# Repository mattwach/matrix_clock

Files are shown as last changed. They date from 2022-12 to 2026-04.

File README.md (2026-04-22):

# matrix_clock
> "I DON’T EVEN SEE THE CODE ANYMORE" - The Matrix.  

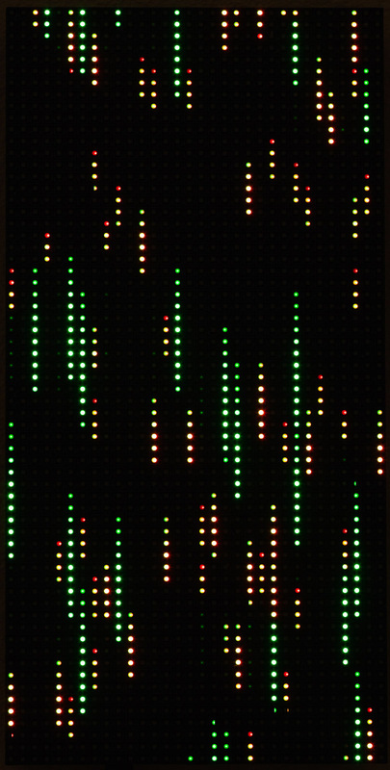
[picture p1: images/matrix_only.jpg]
matrix clock


Shown above is a clock that presents the current time on an 64x32 RGB LED
matrix.  The clock has other selectable modes, including a view that includes
the numbers:

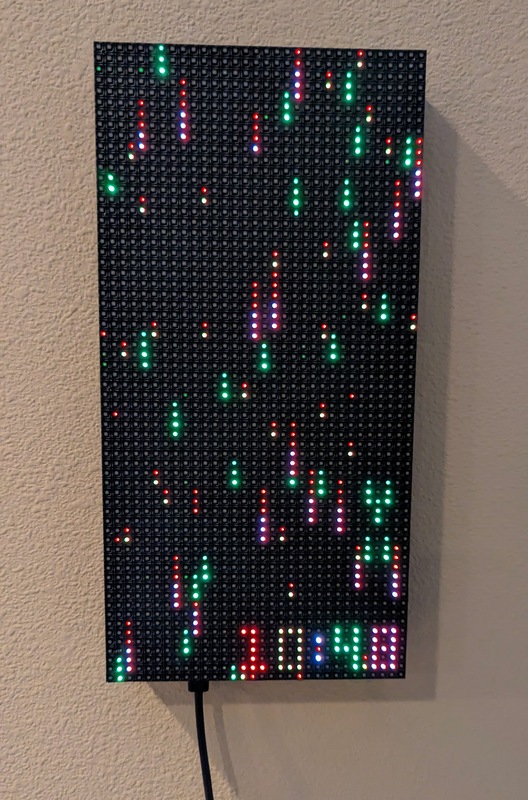
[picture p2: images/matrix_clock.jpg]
matrix clock


and some other selectable views:

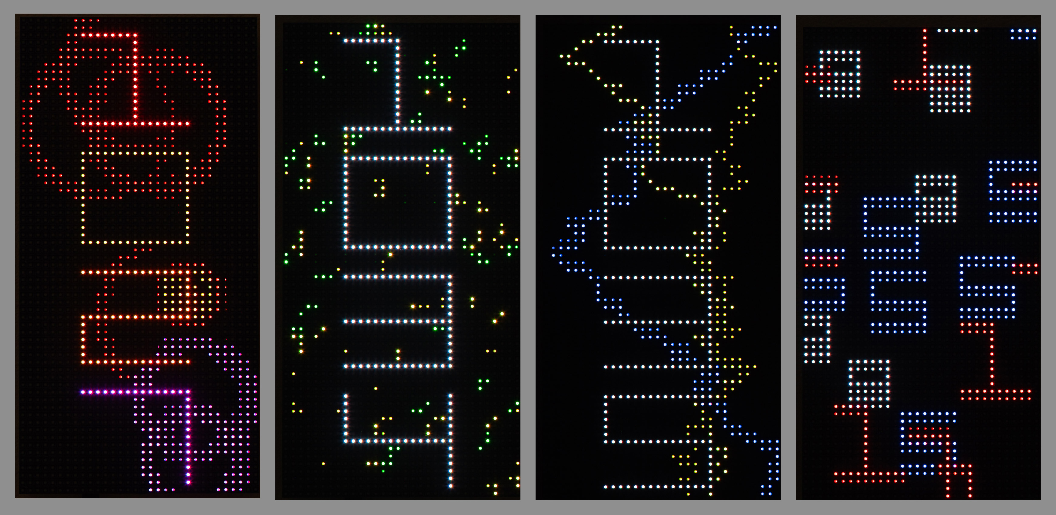
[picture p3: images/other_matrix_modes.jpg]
matrix clock


Although the images above give you a basic idea, they can't show you the
dynamic range of the LED or the visual impression of 200 FPS animations,

The project's firmware is designed to easily incorporate support for other
hardware configurations.  Included is a 8x8 "Dotstar" matrix version that was my
first version:

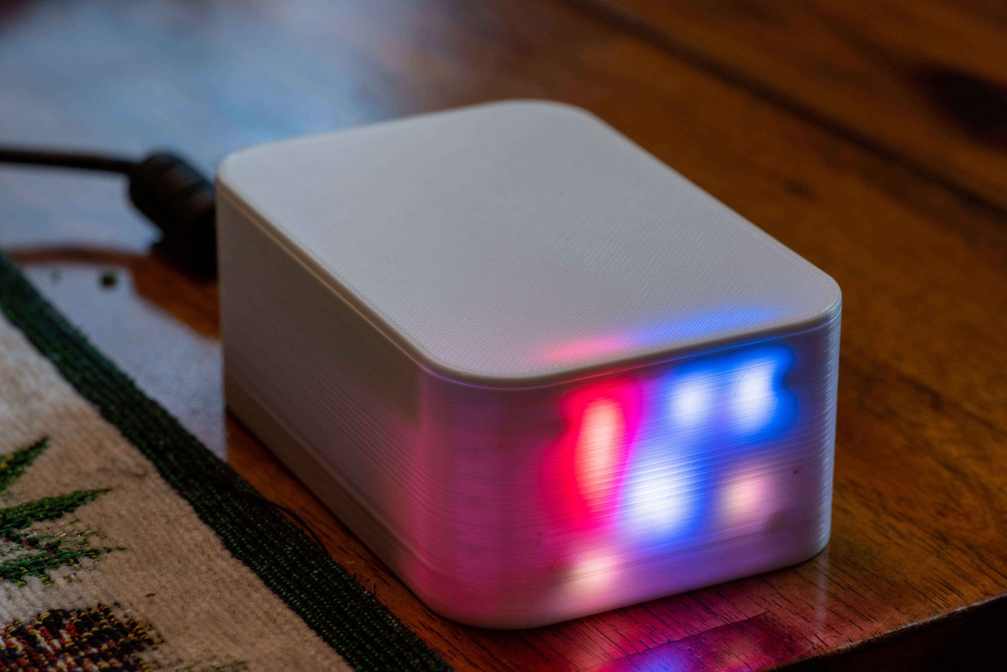
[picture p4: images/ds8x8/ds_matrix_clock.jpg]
matrix clock


*This document* focuses on the newer 62x32-based model, which I prefer.  If you
want to learn more details on the 8x8 build, I have a separate document
for it [here](README_dotstar_8x8.md).

In the upcoming sections, I explain how I built the clock.  I also
explain how to modify the design in different ways.

# Parts List

You can of course modify the design to use different ones.  Prices are "at time
of writing":

   * Microcontroller: [Raspberry PI Pico ($4)](https://www.adafruit.com/product/4864)
   * [LED Matrix 62x32: ($30)](https://www.amazon.com/waveshare-Displaying-Animation-Adjustable-Brightness/dp/B0B3W1PFY6)
     Note there are many vendors of this display - I assume they have similar
     interfaces.
   * Clock: [DS3231-based RTC module ($4)](https://www.amazon.com/HiLetgo-AT24C32-Arduino-Without-Battery/dp/B00LX3V7F0).
     This part is optional-but-recommended. The firmware can be built to use the
     Pi Pico clock libraries but you will lose battery backup and the time
     will drift more. 
   * Buttons: I used [2 6mm push buttons for control (<$1)](https://www.amazon.com/WOWOONE-12x12x7-3-Tactile-Momentary-Assortment/dp/B08JLWTQ3C)
     and one 6x3 SMD button for optional reset capability.
   * Connectors:
     * I used one 8x2 2.54 pitch male pin header to interface the Pico PCB with
       the matrix (using the usually-included interface cable)
     * I used a 2x1 angled 2.54 pitch pin header for connecting the LED to the
       PCB.
     * I used a 3x1 angled 2.54 pitch pin header for connecting the buttons to
       the PCB
   * I used a 220uF capacitor to reduce 5V noise.  Somewhat larger or smaller
     values should also work fine.
   * Circuit board for assembling components.
     * There are many options.  I ended up ordering a PCB from
       http://oshpark.com for the main board because my PCB layout needs a
       two-layer board.  I could have wired it up on perf board, but the large
       number of pin connections would have make it difficult to get a clean
       result.
     * There is a separate PCB for the buttons.  This board is very simple so
       any build technique should be straight-forward.  I used my CNC
       machine to cut a board within an hour.  If you order a main board, you
       might opt to bundle the button pcb with the order. 

Optional:

The LED display can pull over 3A if all LEDs are set to white.  The firmware I
wrote never does this and needs about 100-300 mA for most of the modes
(as-measured with a multimeter).  Thus I'm using the Pi Pico's VDD pin, which is
directly connected to USB power.  This connection should be limited to 500 mA or
less, thus I added the following electronic components to enforce the current
limit:

   * NCP380 current limiting IC
   * Two additional 1uf capacitors for stability.  I am using SMD but ceramic
     through-hole are also an option.

My hardware has this current protection but it has never activated outside of
testing thus one might argue that it's not needed.  If you plan to make your own
display modes, I suggest including the protection.

# Reading the clock

How can the clock be read when no numbers are shown?  By noting the colors and
speed of the particles.  Here is my color mapping for each number, as shown in
the time setting interface:

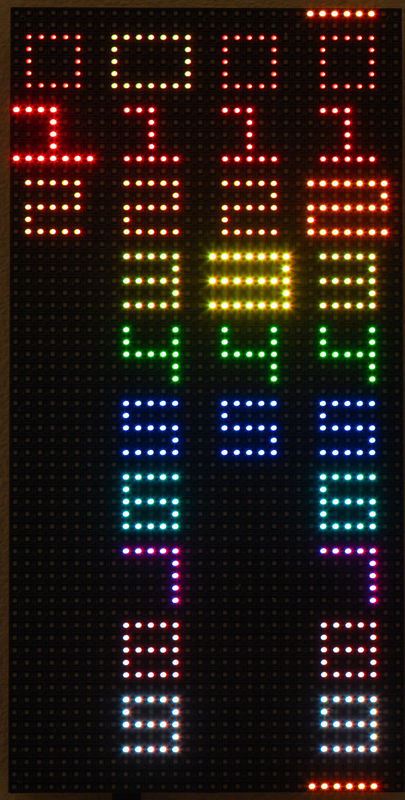
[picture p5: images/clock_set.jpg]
numbers


> Colors are defined in [src/colors.c](src/colors.c) if you would like to edit
> them.

# Feature Overview

This is a quick tour of the built in-features

## Power On

When you plug in the clock via any USB power source you will get a matrix clock
display that indicates the current time as-reported by the RTC clock hardware.

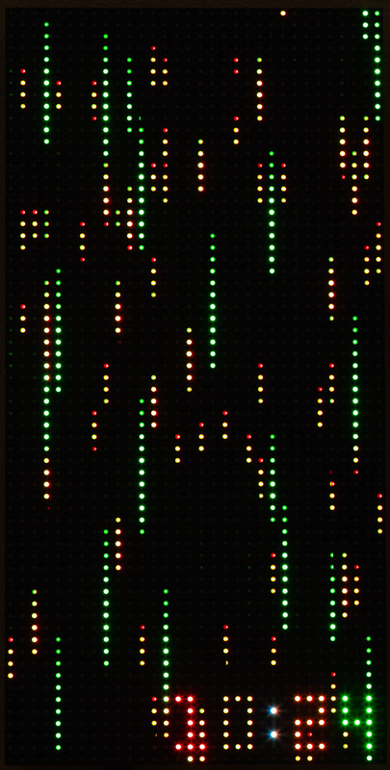
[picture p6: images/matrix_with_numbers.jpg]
matrix clock 2


## Setting the Time

The clock has two buttons on it's side: "set" and "increment". Pressing "set"
goes into time change mode where you can use "set" and "increment" to change
each time digit.

> You can also set the clock via the USB connection.

## Changing the Display Mode

If you press the "increment" button while the matrix is showing, the clock will
cycle through display modes.  Currently defined modes include:

* **Simple** Shows the time with no animations.  The color of the time
  changes throughout the day to approximate a sunrise/daytime/sunset color
  temperature.
* **Matrix With Numbers** The default
* **Matrix Only** For those who want a challenge
* **Bounce** Particles bounce around the numbers. 
* **Number Cascade** Digits fall from the top of the display to the bottom.  The
  size and speed of the digit represent the place in the time (hours vs
  minutes).
* **Waveform** Waveforms progress from the bottom of the display to the top at
  different speeds based on the time digit.
* **Drops** A water droplet effect appears behind the numbers.
* **Off -**  Useful if you want a darkened room.

Each display mode uses color as described earlier to accent the current time.

## Console Configuration

If you plug the clock into a computer, you can run a terminal emulator program
to access many additional settings.  In Linux, I use the "minicom" terminal
emulator and my command looks like this:

```bash
minicom -b 115200 -P /dev/ttyUSB0
```

> The serial device (`/dev/ttyUSB0`) can vary between computers and operating
> systems. 

Once started, you will see something like this:

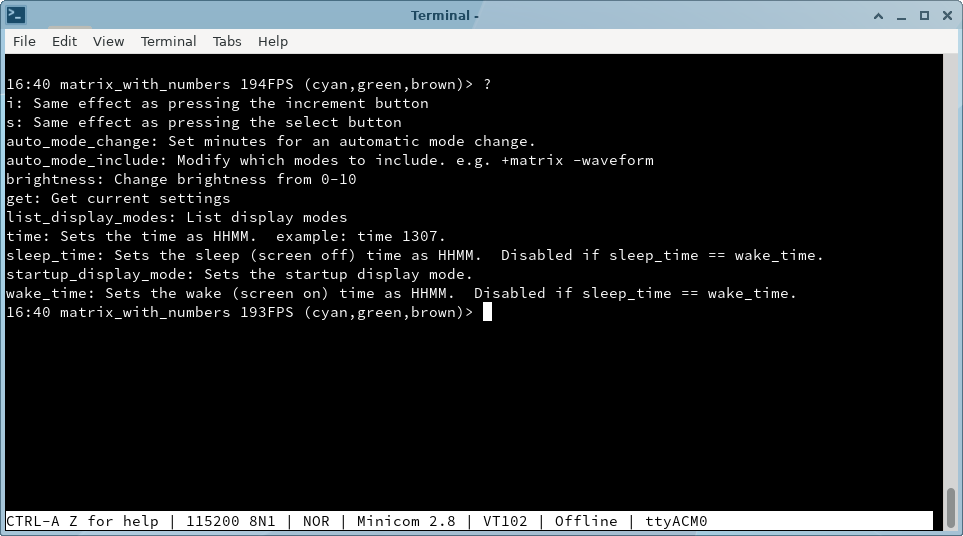
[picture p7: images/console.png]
console


> By default, `minicom` turns on local echo, making my typed characters appear
> twice.  `minicom` allows this to be turned off with `ctrl-a e`.

Type `help` or `?` for help.

# Build Instructions

## Electronics

Here is the schematic for the 64x32 version:

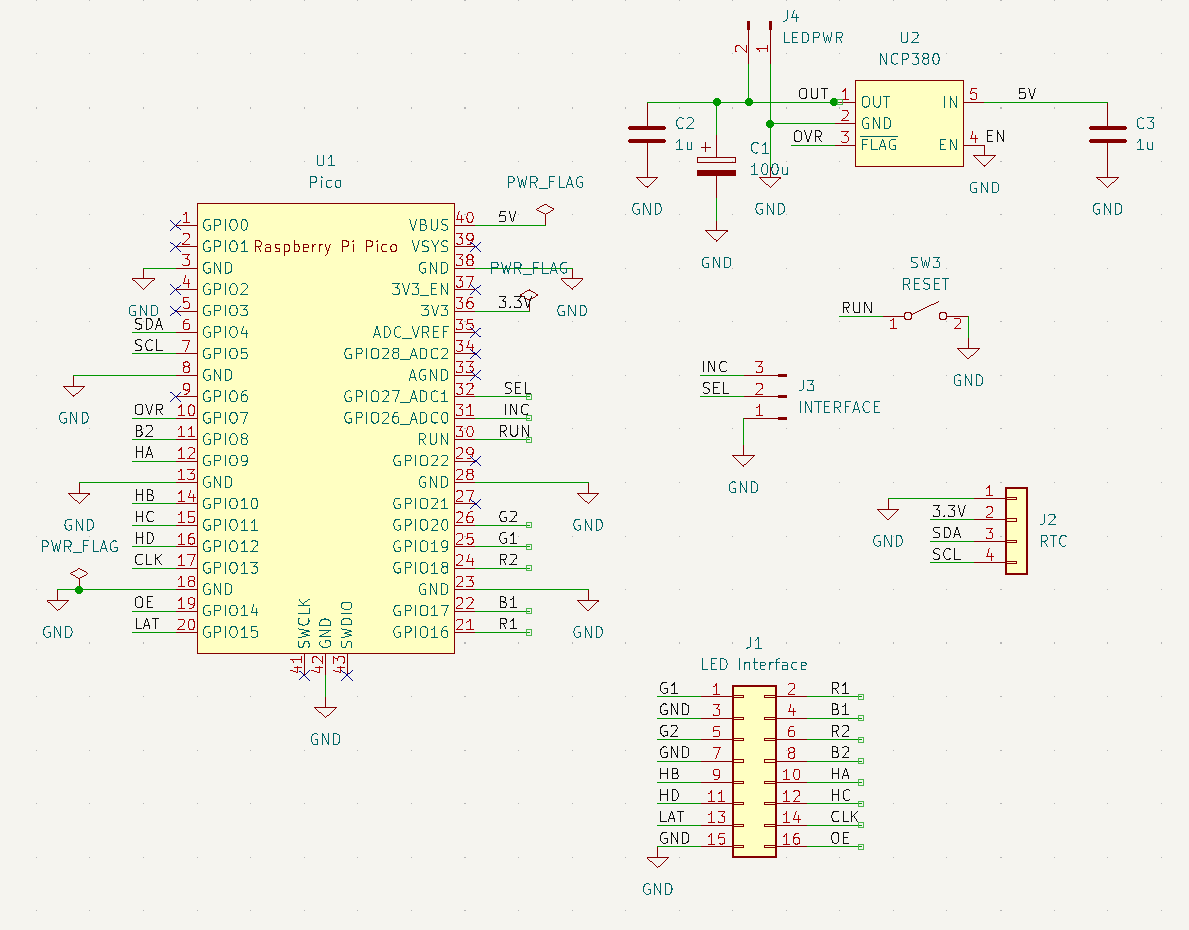
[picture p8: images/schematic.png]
schematic


Here is a description on major components and their purpose:

  - **Pi Pico**: This is the main controller
  - **RTC (Real Time Clock, Optional)**: This provides time to the Pico via an I2C connection.
    You could use alternate clock hardware as described in a later section.  In
    terms of the I2C connection, note that the RTC clock is powered by 3.3V
    instead of the specified 5V.  This is the easiest way to make the clock
    compatible with the 3.3V maximum voltage of the PI Pico.  If your RTC really
    does need 5V, there are solutions but the details are not the focus of this
    document.  Thus I suggest doing a Google search for "3.3 to 5V I2C" to learn
    more.
  - **64x32 matrix**: This is also a 5V part and is connected to the 5V VDD of the
    Pico, allowing ~500mA to be safely consumed by the panel.  The Pico is
    directly connected and will deliver 0-3.3V *signals* to the panel.  Unlike
    I2C for the RTC clock, the LED pins are high impedance inputs with no pullup
    thus there is no hardware risk in connecting them directly to the Pico.  The
    main risk is that the LED panel will not accept 3.3V as a legitimate "high"
    signal and thus it wont work.  For my panel 3.3V was accepted without a
    problem thus no level converters were needed.  I suspect this is the common
    scenario with these panels.
  - **100 uF-470 uF capacitor**.  The actual value is not important other than
    "big".  The purpose of the capacitor is to support the power requirements of
    the LED, which can be a "noisy" load, needing near zero current one moment
    and several hundred mA the next.
  - **Buttons**.  Select, increment and reset as described earlier.
  - **NCP380 current limiting chip (optional)**.  This chip provides insurance for
    the case where you one day decide to change the firmware to light up many
    LEDs and draw too much current.  If you really want to do support high
    current draw, you'll need to rework the power design so that the LED panel
    can be directly powered from a capable (3A+) source instead of VDD on the
    Pico.
    
> VDD on the Pico is a direct passthrough to the USB power so it's the
> USB regulator (wall adapter or computer) and the PCB traces of the Pico that are
> the main power bottlenecks.

> If you don't us use the NCP380, simply connect the Pico VDD pin directly to the LED.
> Keep the 100u capacitor for noise purposes.

In terms of layout, here is the KiCAD layout for the schematic above (with
ground plane hidden):

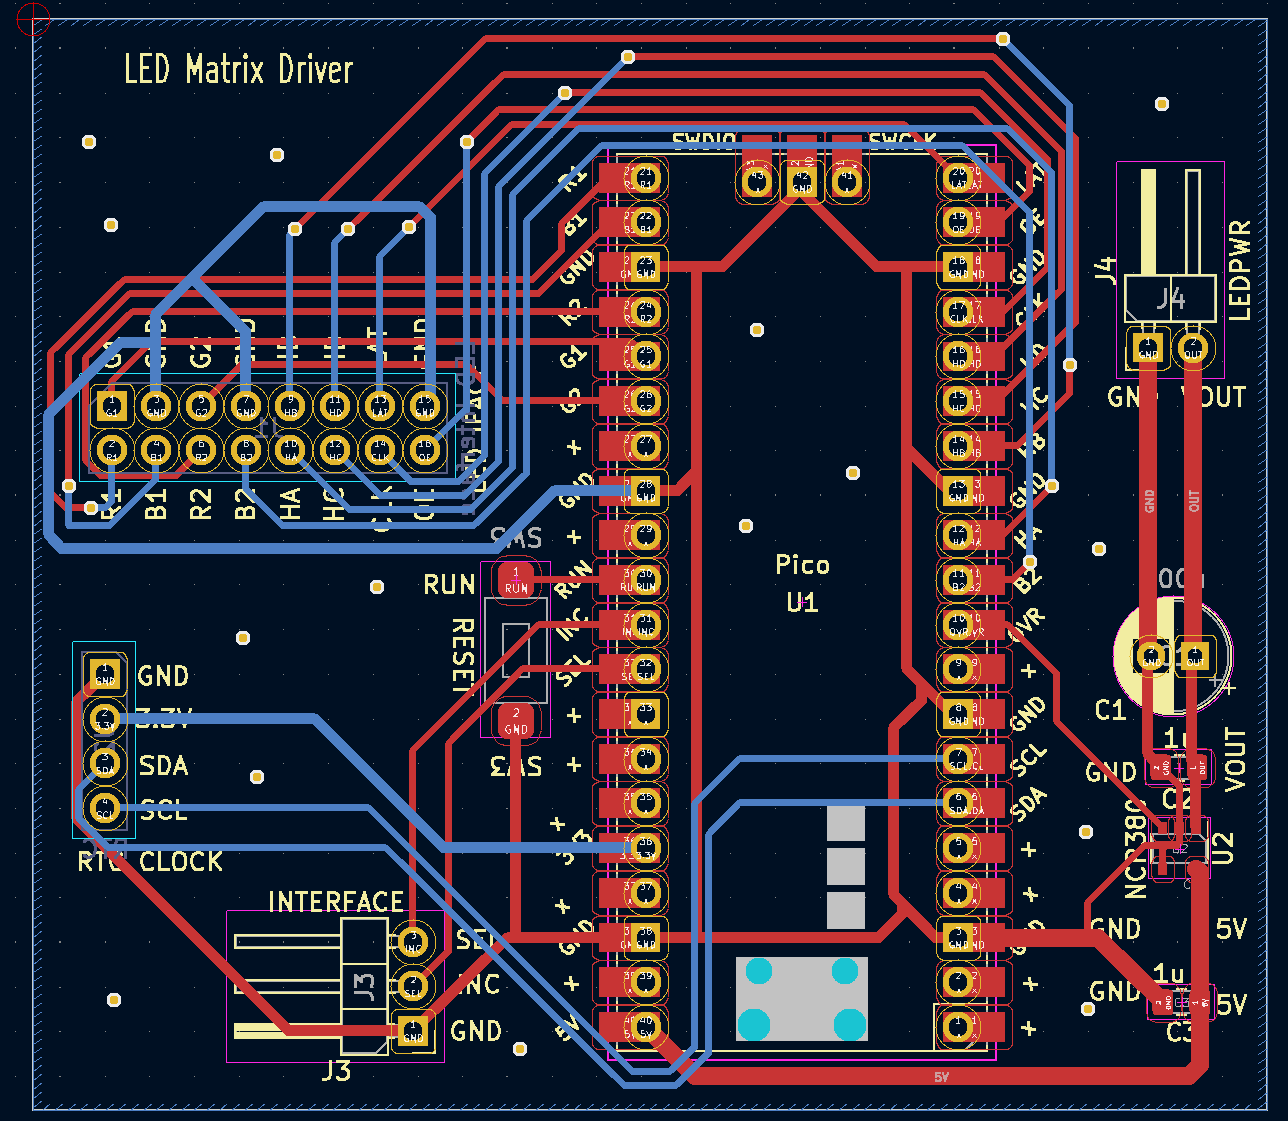
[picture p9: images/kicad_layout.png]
KiCAD layout


and here is a photo of the completed PCB.  Note that the capacitor can't be seen
because it is on the backside of the board:

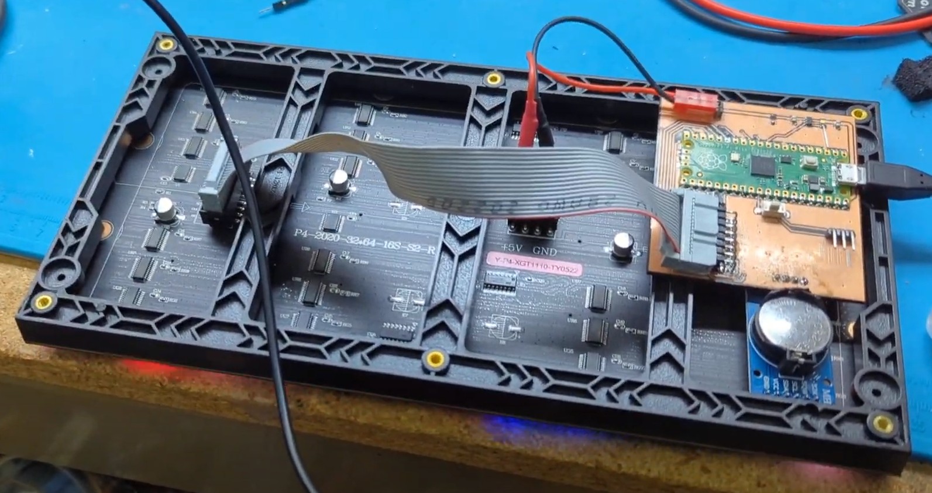
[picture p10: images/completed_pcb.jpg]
completed pcb


As for the buttons, here is the simple KiCAD layout:

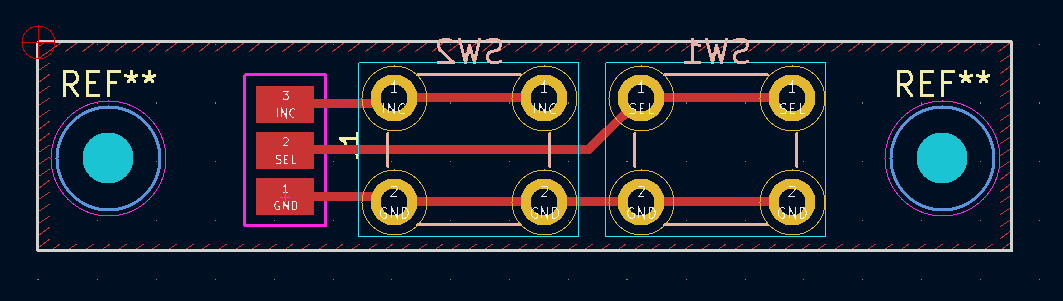
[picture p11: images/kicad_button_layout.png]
KiCAD button layout


and the finished board that I cut out with my CNC machine (just using a perf
board would also work fine):

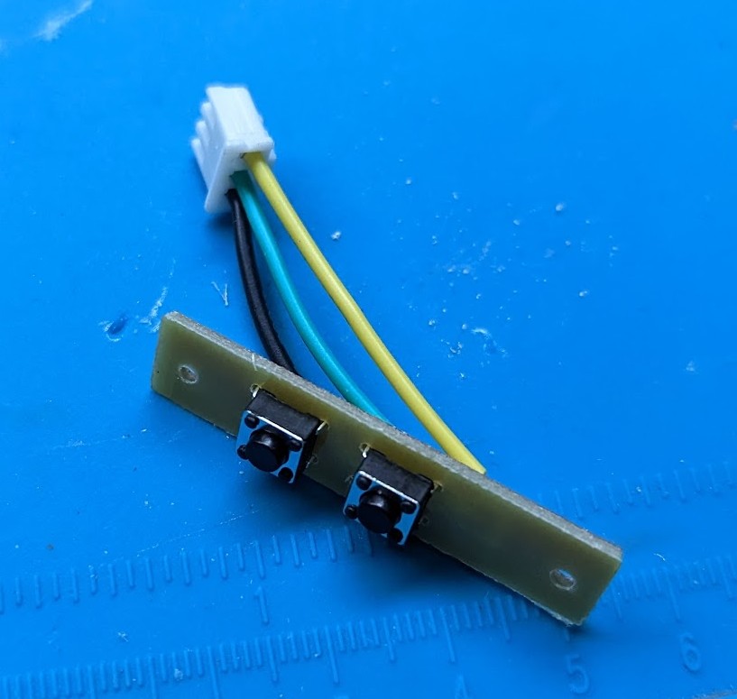
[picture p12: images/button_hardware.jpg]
button hardware


## Firmware

> TLDR: If you don't want to build the firmware (`matrix_clock_led_64x32.uf2`) 
yourself, I have a couple of precompiled versions under the
[firmware](firmware) directory.

Source files (written in C) are  provided in the [src/](src) directory.  If you
have never built PI Pico firmware before, run through the official [Getting
started with the Raspberry Pi
PICO](https://datasheets.raspberrypi.com/pico/getting-started-with-pico.pdf)
documentation first to get the needed tools up-and-running on your system.

The instructions for building the clock firmware are the same as the guide
linked above, but I created a small/simple [bootstrap.sh](src/bootstrap.sh)
script to lessen the number to needed steps:

```bash
./bootstrap.sh 
cd build/
make -j
```

I encourage you to view the contents of [bootstrap.sh](src/bootstrap.sh)
  yourself instead of blindly running it.  You'll see something like this:

```bash
$ cat bootstrap.sh 
#!/bin/bash

if [ ! -f pico_uart_console/CMakeLists.txt ]; then
  git submodule init
  git submodule update
fi

rm -rf build
mkdir build
cd build
cmake ..
```

> If building under Windows, you may opt to run the DOS-equivalent commands
> contained within `bootstrap.sh` manually.  The good news is that there
> are only a few commands to run.

The two major things done here are getting some dependencies (git submodules)
and setting up a new build environment under `build/`

If all went well above, you will have a `src/build/matrix_clock.uf2` file
available to load onto a PI Pico.  Note that
`firmware/matrix_clock_led_64x32.uf2` will not be changed.

# Hardware build

The hardware build is fairly minimalistic, solving the given problems:

  * Securing the PI Pico, RTC hardware and buttons at the bottom of the panel
  * Keeping the connection cables constrained so the clock can mount flat on a
    wall
  * Providing a wall mount

I solved all of these problem by creating a couple of 3D models and printing them out.
I used OpenSCAD for the modeling.

This model is located at
[case/led_matrix_64x32/led_matrix_64x32.scad](case/led_matrix_64x32/led_matrix_64x32.scad).
It can be modified with any text editor and viewed in the free
[OpenSCAD](http://openscad.org) software.

If you don't want to mess around with OpenSCAD, I also have the models available
for direct download at
[case/led_matrix_64x32/export](case/led_matrix_64x32/export).  These are .3mf
files (the successor to .stl format) that most modern slicer programs can
directly load.

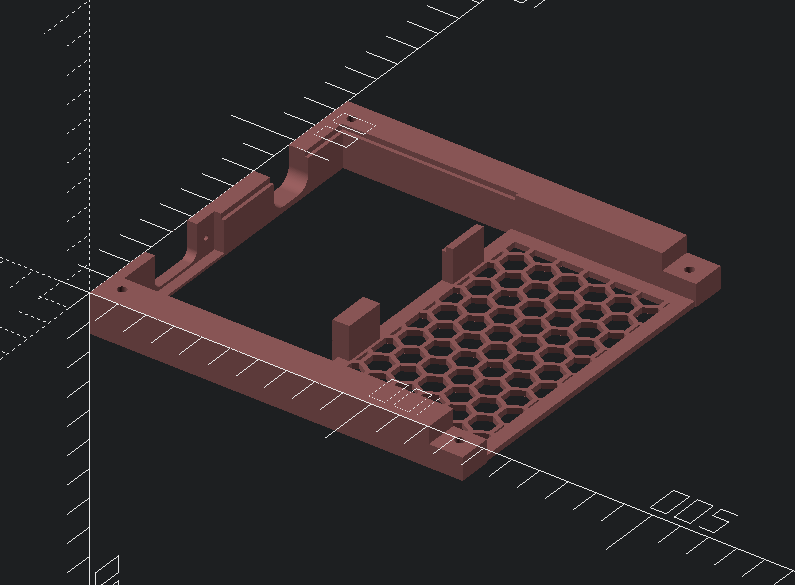
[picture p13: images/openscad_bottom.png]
openscad_bottom

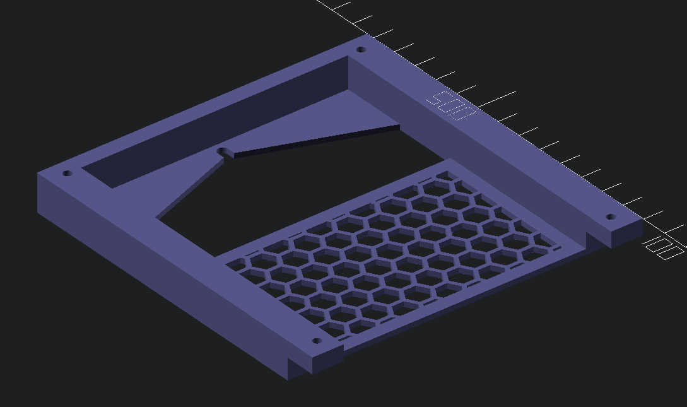
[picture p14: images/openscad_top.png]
openscad_top

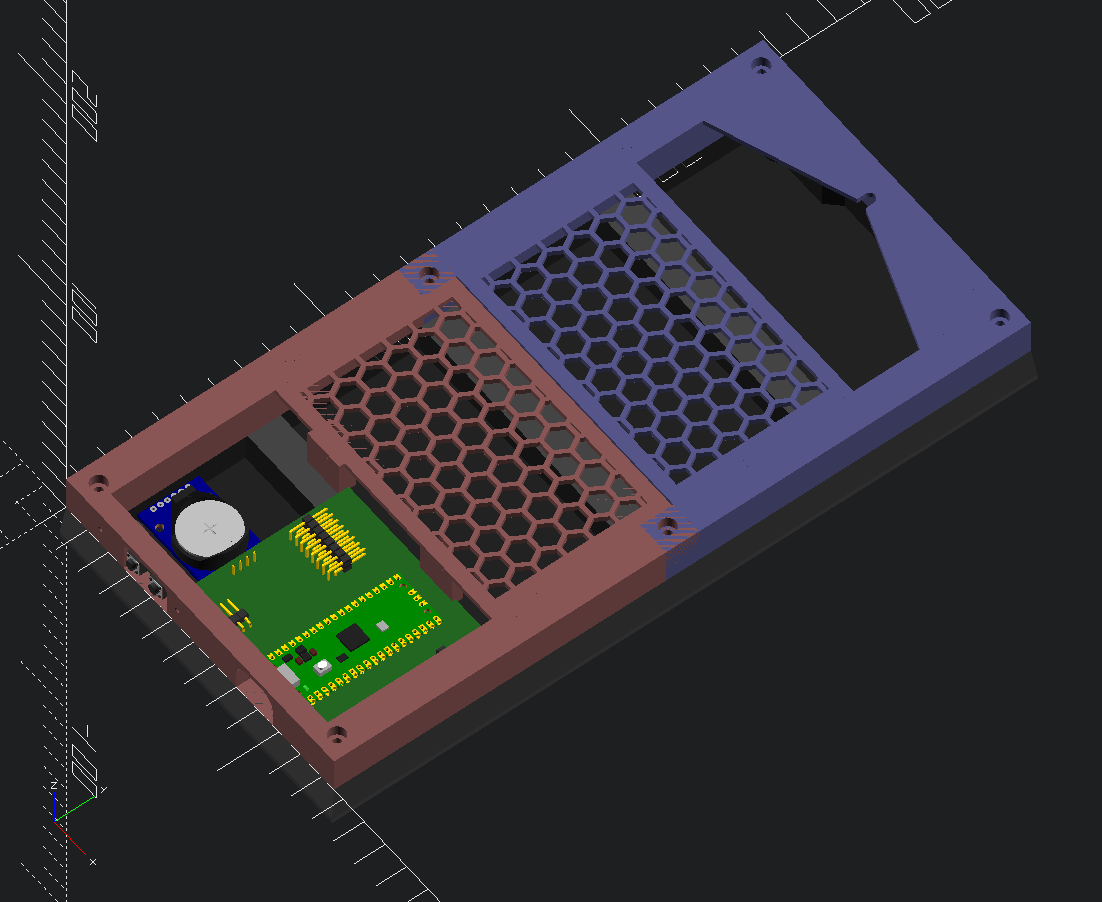
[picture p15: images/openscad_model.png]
openscad_model


To assemble, I used M2 bolts to attach the buttons to the bottom, 6mm long I
think but something in that area should be fine.  I used M3 bolts (around
12-16mm) to attach the 3D printed parts to the led matrix.

The PCB settles into a custom slot in the bottom 3d part (see the grooves in the
red image above) and is held in place with no bolts required, just make sure
it's in the proper position before tightening the frame bolts.

The hex matrixes on the back hold the power and led interface cables within the
unit so that it will mount flush on the wall.  A guide and slot is provided for
wall hanging the unit.

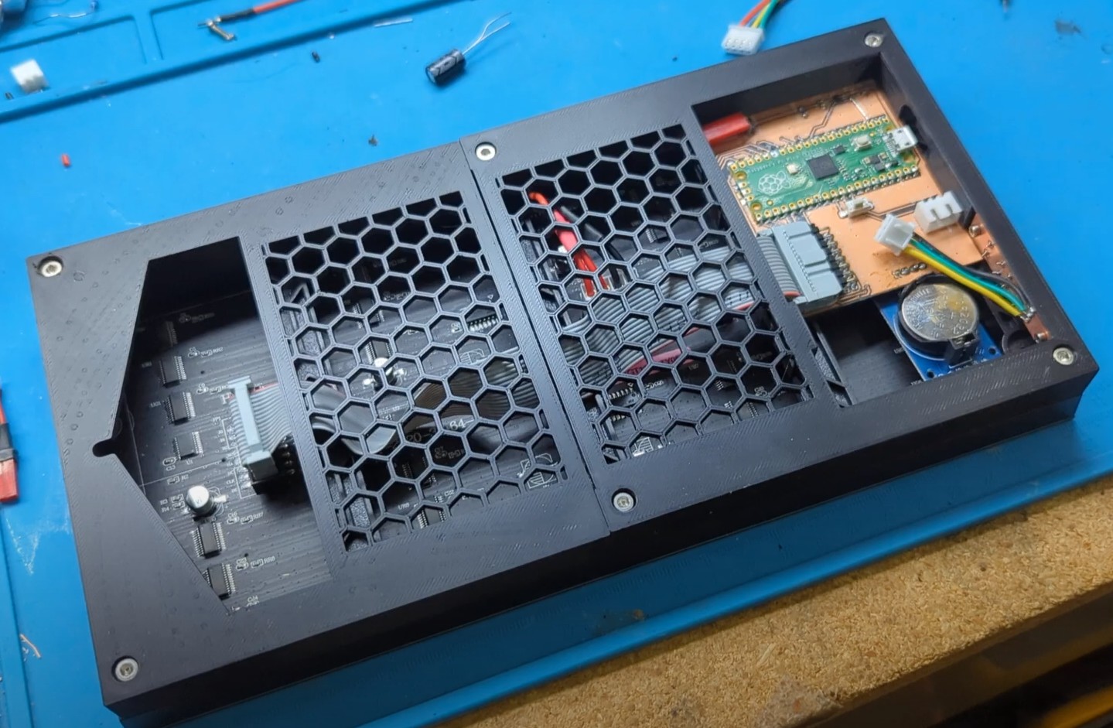
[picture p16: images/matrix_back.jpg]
opened clock


# Customization Guide

This part of the documentation points you in the right direction if you want to
modify the project.  This entire section should be consider optional and more
advanced than others.

## Using Different LED Hardware

The file [src/led_matrix.h](src/led_matrix.h), contains the interface your
hardware driver will be called with.
[src/led_matrix_62x32.c](src/led_matrix_64x32.c) implements it for the 64x32 LED
hardware.  There is also a [src/led_matrix_dotstar.c](src/led_matrix_dotstar.c)
file which is used *instead* when building the dotstar version.  To add
additional hardware support, create a new `.c` file (for example
`src/led_matrix_neopixel.c`) and change [src/CMakeLists.txt](src/CMakeLists.txt)
to point to your new file.c`.  The main function you'll be implementing is:

```c
#define LED_MATRIX_WIDTH 8
#define LED_MATRIX_HEIGHT 8

// render the matrix.
// data is of the form 0xIIRRGGBB where
// II -> Intensity (brightness)
// RR -> Red
// GG -> Green
// BB -> Blue
//
// Values are 0-255
// format is horizontal rows.  The first pixel
// sent is the southwest corner of the matrix.
void led_matrix_render(uint32_t* data);
```

Again, look at [src/led_matrix_dotstar.c](src/led_matrix_dotstar.c) for a
straight-forward implementation of `led_matrix_render`.

## Using Different Clock Hardware

Instead of an RTC, you might want to go with a radio-based clock, a GPS clock,
or [keeping the time with the Pi
Pico](https://raspberrypi.github.io/pico-sdk-doxygen/group__hardware__rtc.html).

> The PICO SDK provides time functions but you'll lose battery backup and
accuracy is not as good as a real RTC.

[src/clock.h](src/clock.h) gives the interface:

```c
// gets the current time in HHMM format (0000 - 2359)
// For example, if 1354 is returned, the time is 13:54 (or
// 1:34 PM if you prefer)
uint16_t clock_get_time();

// Sets the time.  For example: time_hhmm = 1234 would set the
// time to 12:34.  Note that 24h time is always used so 1234
// is 12:34 PM and 0034 is 12:34 AM.
void clock_set_time(uint16_t time_hhmm);
```

and [src/clock_ds3231.c](src/clock_d23231.c) gives a concrete implementation for
the RTC module.  The file [src/clock_pico_internal.c](src/clock_pico_internal.c)
provides an implementation that does not need RTC hardware.  It can be selected
in [src/CMakeLists.txt](src/CMakeLists.txt).

## Adding / Changing Display Modes

There are two files and one directory to consider.  The first file is
[src/clock_render.c](src/clock_render.c).  Specifically, this section:

```c
  struct DisplayMode display_modes[] = {
    {"matrix_with_numbers", matrix_with_numbers_render},  // This entry will be the default power-on mode
    {"matrix", matrix_render},
    {"bounce", bounce_render},
    {"number_cascade", number_cascade_hires_render},
    {"waveform", waveform_render},
    {"drops", drops_render},
    {"off", blank_render},  // always put this entry at the end of the list
  };
```

This section lists the display modes, names them and provides a function pointer
to each one.  If you were to remove a line from this array, or reorder the
lines, you would see the corresponding change when you build/load new firmware.
In order for the function pointers to have any meaning, you'll need to include
the corresponding files:

```c
#include "render/matrix_with_numbers.h"
#include "render/matrix.h"
#include "render/bounce.h"
...
```

Note that, by convention, all rendering functions are defined in the
[src/render](src/render) directory.  Here is an example
[src/render/blank.c](src/render/blank.c):

```c
void blank_render(
    uint32_t* led,
    uint32_t frame_index,
    uint16_t time_hhmm,
    const struct ClockSettings* settings) {
  memset(
    led,
    0,
    LED_MATRIX_WIDTH * LED_MATRIX_HEIGHT * sizeof(uint32_t));
}
```

This simple function simply clears the `led` array to zero which effectively
turns off the display.

The `time_hhmm` provides the time as an integer.  For example, 1:45 AM would be
represented as `0145` and 1:45 PM would be represented as `1345`.

The `frame_index` parameter can be useful for initialization.  It is always set
to `0` when the display mode is made active.

The `settings` structure has several potentially-useful fields but especially
useful is getting the user preference for LED brightness:

```c
  const uint8_t br = brightness_step_to_brightness(settings);
```

This value (0-255), would then be used as a baseline brightness when turning on
LEDs in `led`

## Changing the Console

The file `src/clock_settings.c` contains all of the commands available to the
USB shell.  Adding your own is straight-forward but I suggest skimming through
https://github.com/mattwach/pico_uart_console to get up-to-speed on how the
console works first.

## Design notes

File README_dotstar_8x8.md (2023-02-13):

# matrix_clock
> "I DON’T EVEN SEE THE CODE ANYMORE" - The Matrix.  

matrix clock

Shown above is a clock that presents the current time on an 8x8 RGB LED matrix.  It's not readable to a passer-by but one can learn to read it with practice.

Here I explain how to build the clock above.  I also explain how to modify the design in different ways.

# Parts List

Here are the parts I used to build the pictured version.  You can of course modify the design to use different ones:

   * Microcontroller: [Raspberry PI Pico ($4)](https://www.adafruit.com/product/4864)
   * LED Matrix: [Adafruit Dotstar 8x8 ($25)](https://www.adafruit.com/product/3444)
   * Clock: [DS3231-based RTC module ($4)](https://www.amazon.com/HiLetgo-AT24C32-Arduino-Without-Battery/dp/B00LX3V7F0)
   * Buttons: [2 12x12 pushbuttons for control (<$1)](https://www.amazon.com/WOWOONE-12x12x7-3-Tactile-Momentary-Assortment/dp/B08JLWTQ3C), 1 6x3 SMD reset button (optional)
   * Connector: 1 4x1 JST-XR male-female pair for connecting the LED matrix
   * 1 220uF capacitor to reduce 5V noise
   * PCB for assembly (however you want to build it.  maybe something like [this](https://www.amazon.com/DEYUE-Double-sided-Prototyping-Solder-able-Protoboards/dp/B07FFDFLZ3))

# Reading the clock

Here is my scheme for showing the time, which you can easily modify to your preference.

Numbers are represented by colors.  At the time of writing, they are as follows:

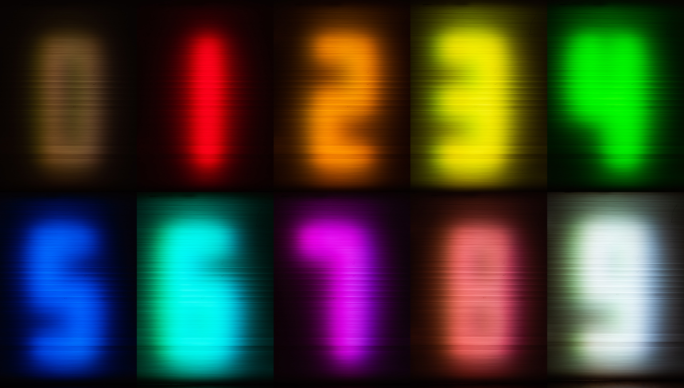
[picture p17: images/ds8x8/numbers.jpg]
numbers


> Colors are defined in [src/colors.c](src/colors.c) if you would like to edit them.

As for the individual digits in the time, these are represented by the speed at
which the matrix points fall:

| digit | speed  |
|---|---|
| Hour - ones place | slow |
| Minute - tens place | medium |
| Minute - ones place | fast |

Here are some examples:

| 12h time | 24h time | Slow point | Medium Point | Fast Point |
|---|---|---|---|---|
| 12:00 AM | 00:00 | brown | brown | brown |
| 12:15 AM | 00:15 | brown | red | blue |
| 1:37 PM  | 13:37 | yellow | yellow | magenta |
| 11:37 PM | 23:37 | yellow | yellow | magenta |

If you are wondering about the hour's tens place, the clock doesn't show it.  I thought it made the clock easier to read but you'll have
to be aware of the time-of-day enough to determine in the tens place yourself.

> Note that the clock has other easier-to-read modes that show actual numbers,  More on that later.

# Feature Overview

This is a quick tour of the built in-features

## Power On

When you plug in the clock via any USB power source you will get a matrix clock display that indicates the current time as-reported by the internal clock module.

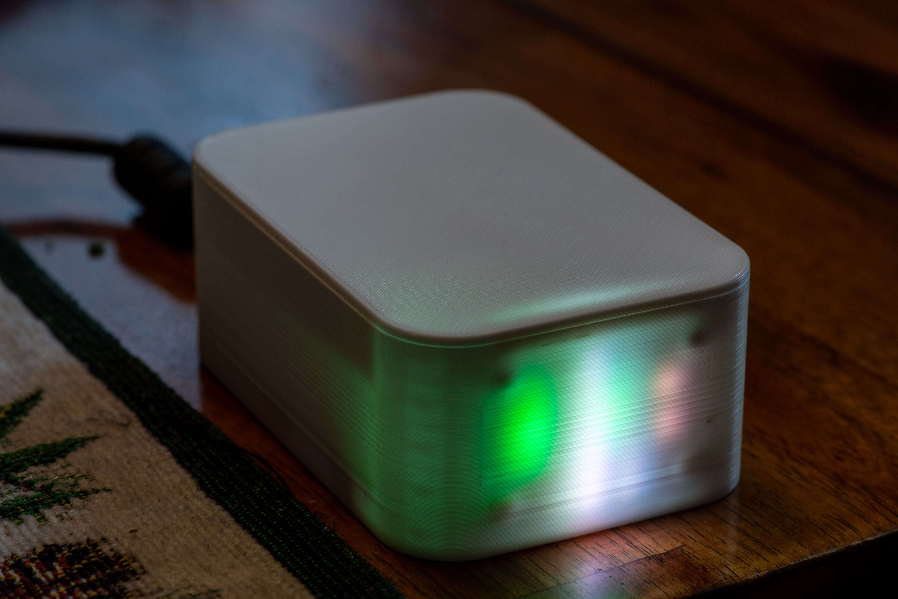
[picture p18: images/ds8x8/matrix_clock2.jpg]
matrix clock 2


## Setting the Time

The clock has two buttons on it's side: "set" and "increment".

   * If you press the *set* button once, the clock will show the current hours as numbers.  You can use the *increment* button to change the hour.
   * If you press the *set* button again, the clock will show the current minutes.  You can use the *increment* button to change the minute.
   * If you press the *set* button a third time, the clock will return to showing the matrix display

> You can also set the clock via the USB connection.

## Changing the Display Mode

If you press the "increment" button while the matrix is showing, the clock will
cycle through display modes.  Currently defined modes include:

* **Matrix -** The default
* **Time scroll -**, similar to matrix mode but uses numbers so it's easier to read
* **Time fade -**.  Uses bigger numbers so even easier to read
* **Binary digits -**  Uses binary symbols in place of digits. Unfortunately my plastic case diffuses the pixels too much for this mode to work well for me, but it would work better with alternate case designs.
* **Off -**  Useful if you want a darkened room.

## Console Configuration

If you plug the clock into a computer, you can run a terminal emulator program to access additional settings.  In Linux, I use the "minicom" terminal emulator and my command looks like this:

```bash
minicom -b 115200 -P /dev/ttyUSB0
```

> The serial device (`/dev/ttyUSB0`) can vary between computers and operating systems. 

Once started, you will see something like this:

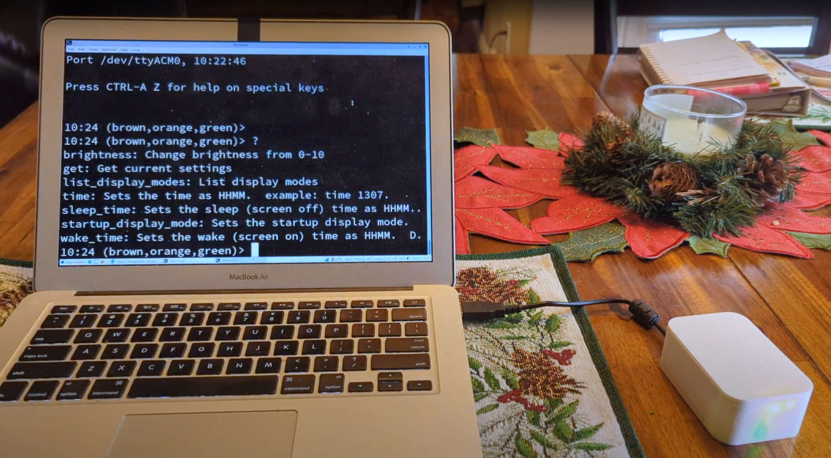
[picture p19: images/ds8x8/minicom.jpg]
minicom


By default, `minicom` turns on local echo, making my typed characters appear twice.
`minicom` allows this to be turned off with `ctrl-a e`.

Type `help` or `?` for help.  Basic options include:

   * Changing LED brightness
   * Changing the time
   * Setting a sleep/wake time where the clock LEDs will automatically turn off.

# Build Instructions

## Electronics

Here is the schematic:

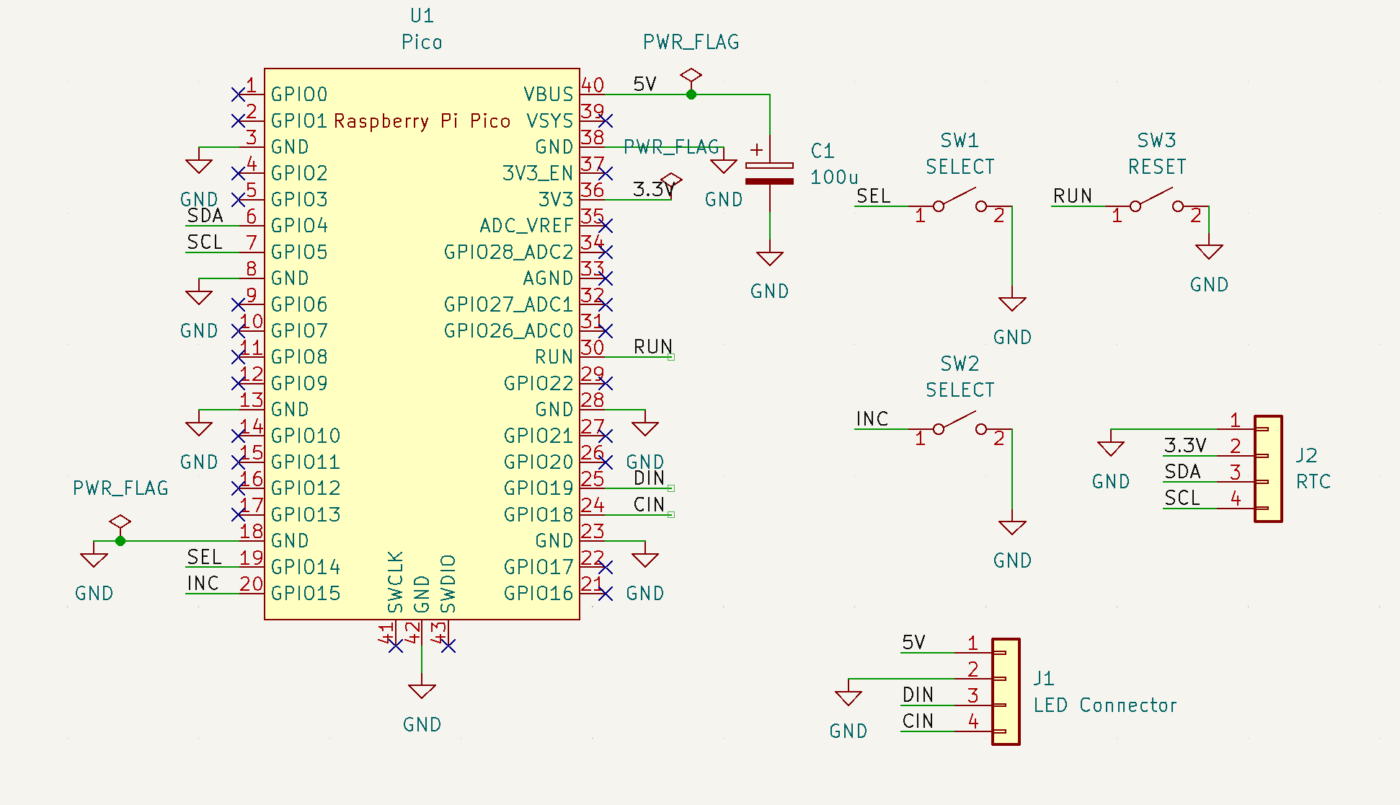
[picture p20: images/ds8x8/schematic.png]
schematic


In terms of an electronic project, the schematic is simple.

Outside of the obvious parts (LED Matrix, PI Pico, RTC, buttons, connectors), there
is a single capacitor.  This capacitor exists to help out the 5V power supply
connected to the clock.  Basically the LED matrix can be a very "noisy load"
drawing almost zero current one instant and quite a bit more the next (depending
on how many LEDs are lit).  The presents a challenge to the 5V regulator.  It
can also lead to voltage spikes due to natural induction properties in the power
wires.  Since the exact properties of the voltage regulator and connection wires
are unknown and variable, it's hard to say how much capacitance (if any) is
needed but adding some capacitance wont hurt anything and could resolve issues
(like random resets) in otherwise-marginal cases.  The size you choose for the
capacitor is up to you but bigger is a bit better you want to to play it extra
safe.

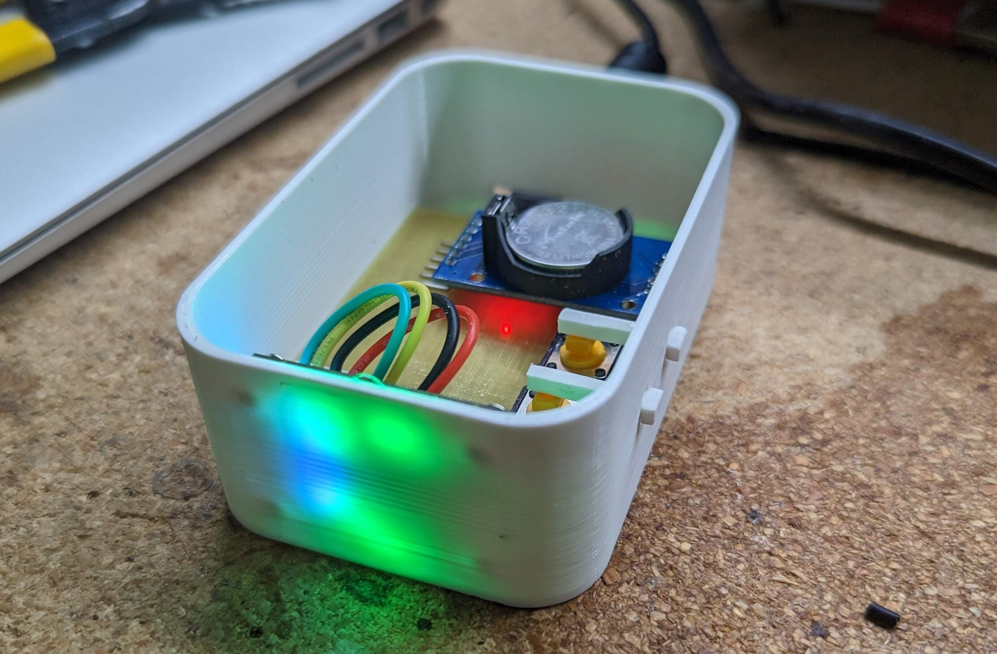
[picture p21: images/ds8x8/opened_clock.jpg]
opened clock


Talking a bit more about the schematic:

The PI Pico connects to the RTC (Real time clock) with a
[I2C](https://en.wikipedia.org/wiki/I%C2%B2C) connection.  There is a bit of a
tripping point here.  Most RTC modules ask for 5V but the Pico is 3.3V.  If you
provide 5V to the RTC, pullup resistors that are almost always included on the
RTC PCB will pull the SDA and SCL lines to 5V which the Pico does not support.
One solution is to remove these pullup resistors and provide your own pullup
resistors to 3.3V instead.  In my case (and likely yours too) an even easier
solution is avaiable.  I simply power the RTC with 3.3V instead of 5V and it
still works fine.

I'm using a Dotstar 8x8 LED matrix.  This matrix uses a protocol that is
compatible with [SPI](https://en.wikipedia.org/wiki/Serial_Peripheral_Interface)
and thus we use the Pico SPI hardware to do the communications.  Alternatives
LED matrix hardware includes [Neopixel](https://www.adafruit.com/product/1487)
and the ["city sign" 16-pin protocol](https://www.adafruit.com/product/420).  If
you want to go with one of these, you'll need to adjust the hardware connections
accordingly - getting them working as an isolated demo is something I would
consider a prerequisite.

There are three buttons.  One is an optional "Reset" button.  If the RUN *pin*
is pulled to ground, the chip is reset.  This is mostly useful for loading new
firmware.  You press reset while holding down the BOOTSEL button on the pico and
it will be ready to accept new firmware.  Without a reset button, you can still
load firmwre but will need to hold BOOTSEL on plugin.

The other buttons are "set" and "increment" as-described in an earlier section.  These utilize the Pico's built in pullup resistor option to implement a button.  Press the button and the signal will be pull down from 3.3V (due to the internal pullup) to 0V and the press will be detected by the hardware/firmware.

## Firmware

> TLDR: If you don't want to build the firmware (`matrix_clock.uf2`) yourself, I
have a precompiled version under the [firmware](firmware) directory.

Source files (written in C) are  provided in the [src/](src) directory.  If you have never built PI Pico firmware before, run through the official [Getting started with the Raspberry Pi PICO](https://datasheets.raspberrypi.com/pico/getting-started-with-pico.pdf) documentation first to get the needed tools up-and-running on your system.

The instructions for building the clock firmware are the same as the guide
linked above, but I created a small/simple [bootstrap.sh](src/bootstrap.sh)
script to lessen the number to needed steps:

```bash
./bootstrap.sh 
cd build/
make -j
```

I encourage you to view the contents of [bootstrap.sh](src/bootstrap.sh) yourself instead of blindly running it.  You'll see something like this:

```bash
$ cat bootstrap.sh 
#!/bin/bash

if [ ! -f pico_uart_console/CMakeLists.txt ]; then
  git submodule init
  git submodule update
fi

rm -rf build
mkdir build
cd build
cmake ..
```

The two major things done here are getting some dependencies (submodules) and setting up a new build environment under `build/`

If all went well above, you will have a `build/matrix_clock.uf2` file available to load onto a PI Pico.

# 3D Printed Case

The 3D printed case is available at [case/matrix_clock_case.scad](case/matrix_clock_case.scad)

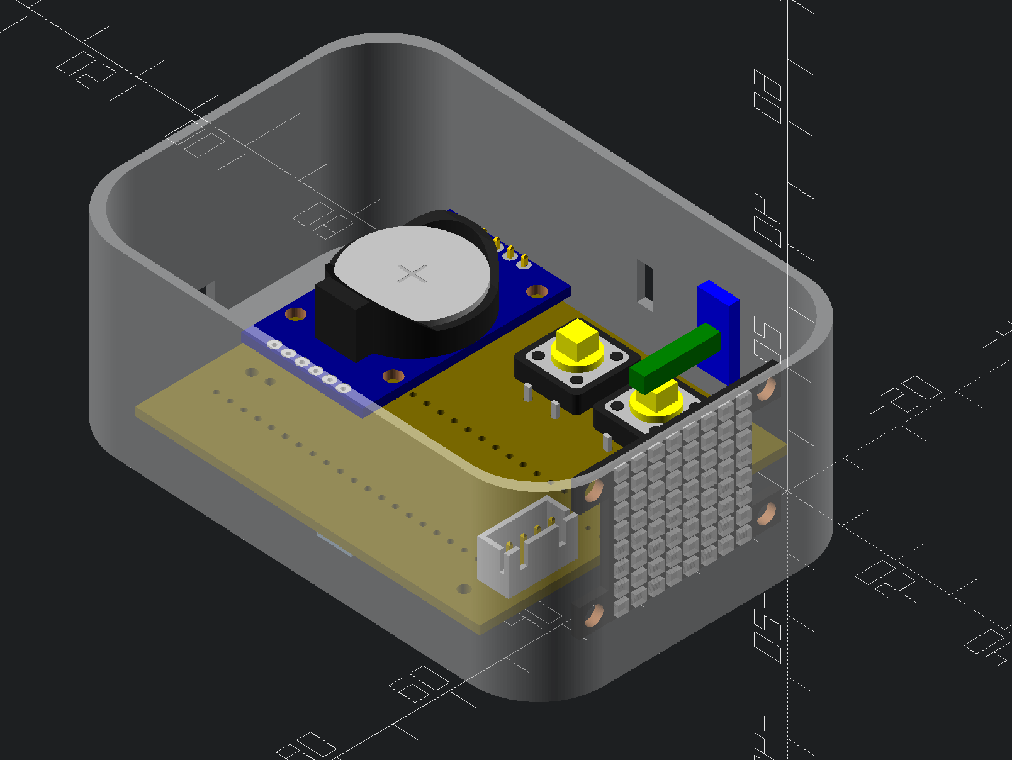
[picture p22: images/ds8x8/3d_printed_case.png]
3d printed case


Looking at the underside, we can see the PICO.  There are also some access ports for the BOOTSEL and reset buttons (for convienent firmware reloading):

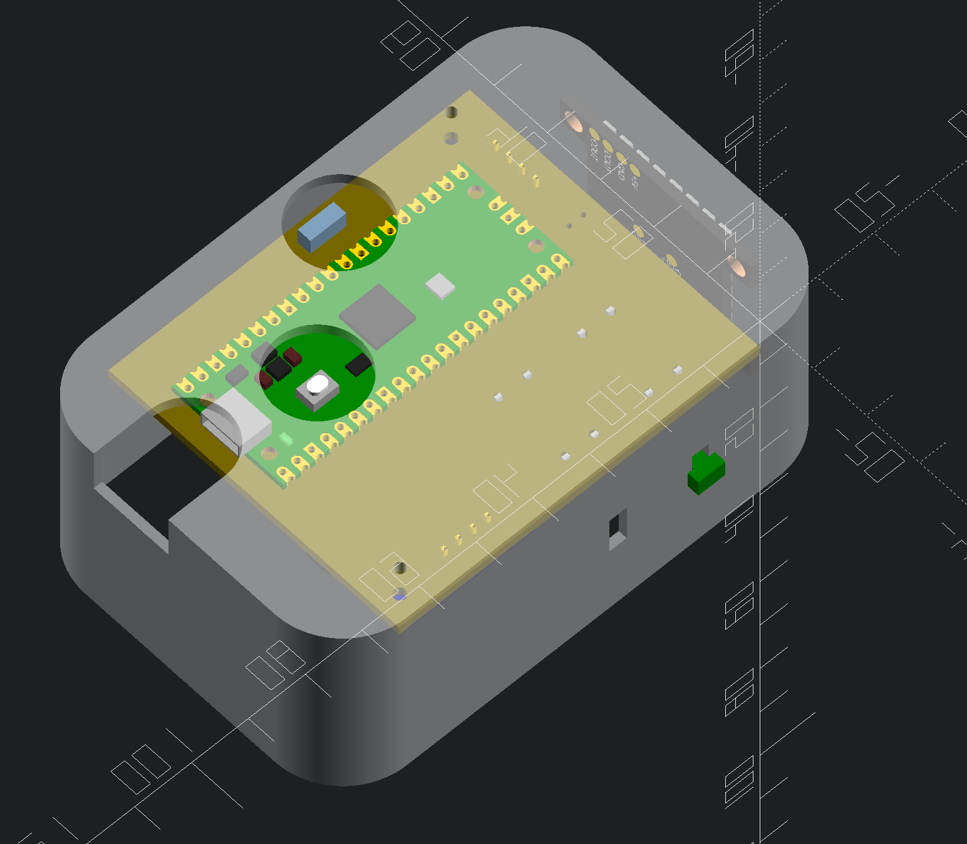
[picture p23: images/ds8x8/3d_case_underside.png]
case underside


If you don't want to mess around with OpenSCAD, you can look at the [case/3mf](case/3mf) directory for files you can load directly into your slicer program.  The same directory also has the file [3mf/prusa_slicer_project.3mf](3mf/prosa_slicer_project.3mf) which can be loaded into Prusa slicer if you happen to use that software.

If you do want to dig into OpenSCAD, I'll point to these lines specifically:

```openscad
  button_peg_shaft();
  button_peg_backing();
  ...
  *top_cover();
  clock_base();
```

These represent the major printable parts.  You can place a `*` in front of a part to hide it or a `!` in front of it to show it in isolation.

A few of other notes about the design:

* The spacing between the LED matrix and front wall leads to a fairly diffused display.  This looks fine in the "matrix" mode but blurry when displaying numbers.  If you want to more readable numbers, you may want to inset a grid into the front to help guide the light.  Keep in mind that the LED matrix does produce some heat while it is running.
* I intentionally set the matrix spacing to allow for some light to leak into the rest of the case.  I like the resulting effect but you could mask off the light paths if you would prefer the back of the case remain dark.
* I would consider the button design "ok" but not "great".  I'd suggest rethinking the design if you plan to use the buttons often.  The current design uses the backing plate for leverage (blue in the image above).  The fit is intentionally tight and might require some light sanding to get it on.  After you get the feel correct, you fix the backing into place with a touch of CA glue.

# Cusomization Guide

This part of the documentation points you in the right direction if you want to modify the project.

## Using Different LED Hardware

The file [src/led_matrix.h](src/led_matrix.h), contains the interface your
hardware driver will be called with.
[src/led_matrix_dotstar.c](src/led_matrix_dotstar.c) implements it for the 8x8
dotstar case.  To use your own, create a new `.c` file (such as
`src/led_matrix_neopixel.c` and change `CMakeLists.txt` to point to your new
file instead of `led_matrix_dotstar.c`.  The main function you'll be
implementing is:

```c
#define LED_MATRIX_WIDTH 8
#define LED_MATRIX_HEIGHT 8

// render the matrix.
// data is of the form 0xIIRRGGBB where
// II -> Intensity (brightness)
// RR -> Red
// GG -> Green
// BB -> Blue
//
// Values are 0-255
// format is horizontal rows.  The first pixel
// sent is the southwest corner of the matrix.
void led_matrix_render(uint32_t* data);
```

again, look at [src/led_matrix_dotstar.c](src/led_matrix_dotstar.c) for a concrete exmaple of an implementation of `led_matrix_render`.  It's really not much code for the dotstar case.

## Using Different Clock Hardware

Instead of an RTC, you might want to go with a radio-based clock, a GPS clock, or [keeping the time with the Pi Pico](https://raspberrypi.github.io/pico-sdk-doxygen/group__hardware__rtc.html) (requiring the user to set the time whenever the power is removed).

[src/clock.h](src/clock.h) gives the interface:

```c
// gets the current time in HHMM format (0000 - 2359)
// For example, if 1354 is returned, the time is 13:54 (or
// 1:34 PM if you prefer)
uint16_t clock_get_time();

// Sets the time.  For example: time_hhmm = 1234 would set the
// time to 12:34.  Note that 24h time is always used so 1234
// is 12:34 PM and 0034 is 12:34 AM.
void clock_set_time(uint16_t time_hhmm);
```

and [src/clock.c](src/clock.c) gives a concrete implementation for the RTC module.

## Changing The Display Rendering

There are two files and one directory to consider.  The first file is [src/clock_render.c](src/clock_render.c).  Specifically, this section:

```c
struct DisplayMode display_modes[] = {
  {"normal", matrix_render},  // This entry will be the default power-on mode
  {"number_cascade", number_cascade_render},
  {"number_fade", fade_render},
  {"binary_grid", binary_grid_render},
  {"off", blank_render},  // always put this entry at the end of the list
};
```

This section lists the display modes, names them and provides a function pointer to each one.  If you were to remove a line from this array, or reorder the lines, you would see the corresponding change when you build/load new firmware.  In order for the function pointers to have any meaning, you'll need to include the corresponding files:

```c
#include "render/blank.h"
#include "render/fade.h"
#include "render/matrix.h"
#include "render/number_cascade.h"
#include "render/number_grid.h"
```

Note that, by convention, all rendering functions are defined in the [src/render](src/render) directory.  Here is an example [src/render/blank.c](src/render/blank.c):

```c
void blank_render(
    uint32_t* led,
    uint32_t frame_index,
    uint16_t time_hhmm,
    const struct ClockSettings* settings) {
  memset(
    led,
    0,
    LED_MATRIX_WIDTH * LED_MATRIX_HEIGHT * sizeof(uint32_t));
}
```

This simple function simply clears the `led` array to zero which effectively turns off the display.

Showing actual patterns will generally require use of the other parameters, such as `time_hhmm`.

The `frame_index` parameter can be useful for initilization.  It is always set to `0` when the display mode is made active.

The `settings` structure has several potentially-useful fields but especially useful is getting the user preference for LED brightness:

```c
  const uint8_t br = brightness_step_to_brightness(settings);
```

This value (0-255), would then be used as a baseline brightness when turning on leds in `led`

## Changing the Console

The file `src/clock_settings.c` contains all of the commands available to the
USB shell.  Adding your own is straight-forward but I suggest skimming through
https://github.com/mattwach/pico_uart_console to get up-to-speed on how the
console works first.

## Using a Different Microcontroller

The hardware requirements for the microcontroller are not demanding for this project (as implemented anyway).  Going with AVR, ESP, STM, PIC or something else would all work perfectly fine.  The main difficulty will be adapting the firmware, specifically:

* The CMake build system
* Access to the PI Pico SDK

To work around these, I would suggest copying the source files to a new project folder, use the "default" build system for your microcontroller and addressing the compiler errors one by one.  Remember that since PI Picos are only $4 and are readily available (at the time I write this) the motivation for going through this effort might not be immediately obivous to others.

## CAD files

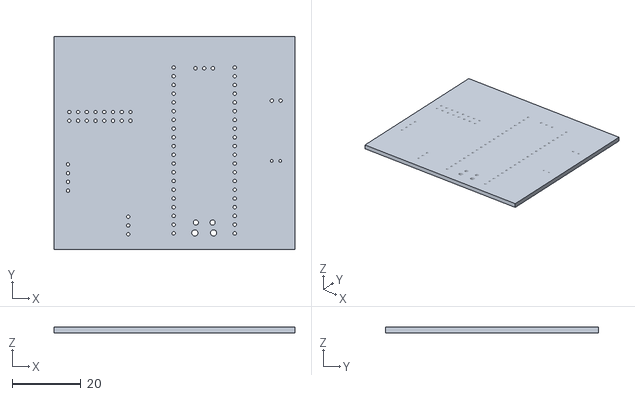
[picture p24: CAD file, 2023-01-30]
case/led_matrix_64x32/dep/main_pcb.stl
70.1 x 62.0 x 1.60

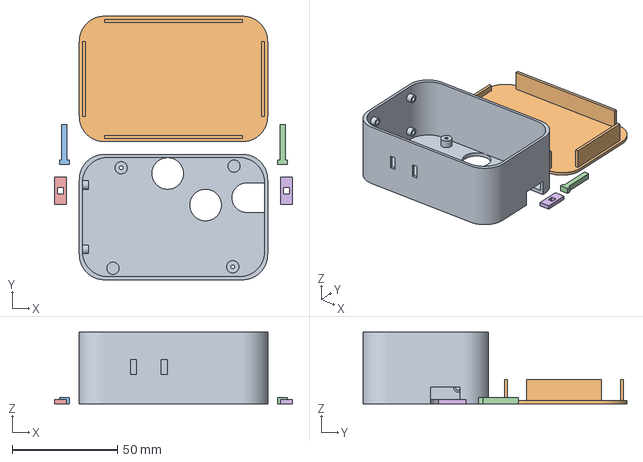
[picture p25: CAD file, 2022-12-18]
case/dotstar_8x8/3mf/prusa_slicer_project.3mf
113.0 x 125.2 x 34.0 mm

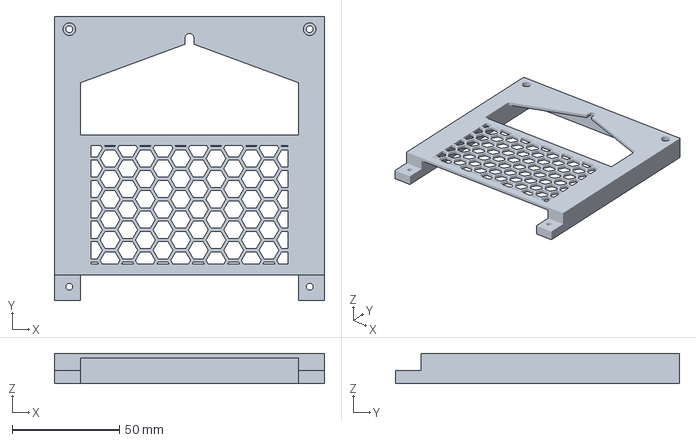
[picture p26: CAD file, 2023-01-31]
case/led_matrix_64x32/export/top_support.3mf
125.8 x 132.5 x 14.0 mm

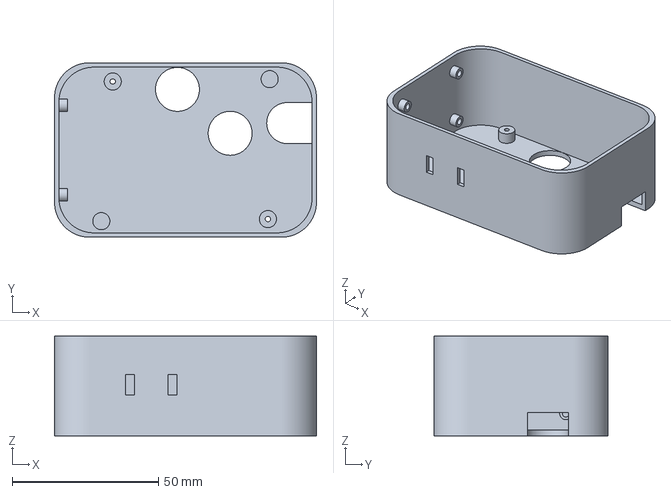
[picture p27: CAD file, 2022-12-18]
case/dotstar_8x8/3mf/base.3mf
89.5 x 59.6 x 34.0 mm

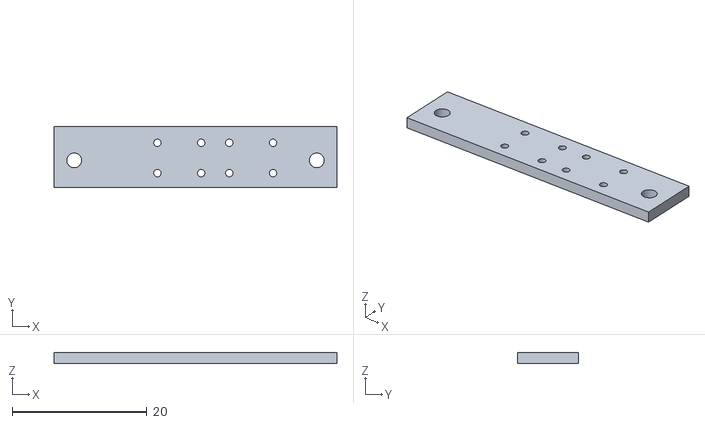
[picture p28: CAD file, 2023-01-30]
case/led_matrix_64x32/dep/button_pcb_kicad.stl
42.0 x 9.00 x 1.60

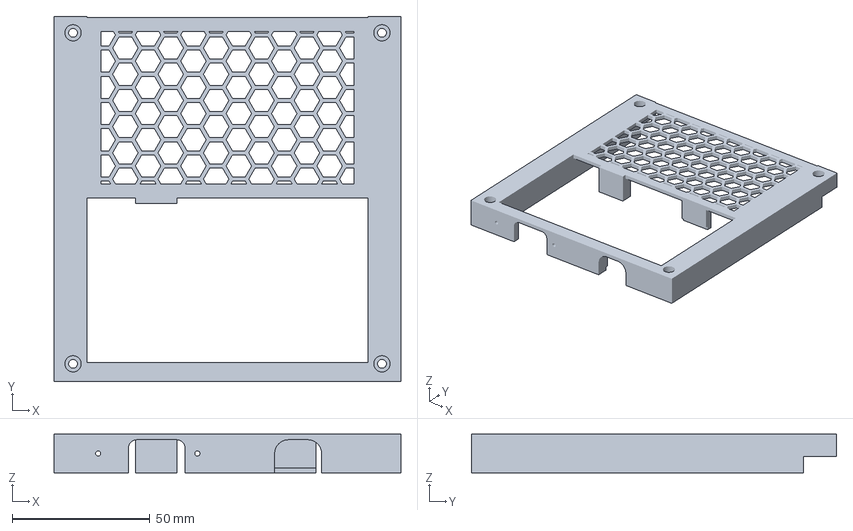
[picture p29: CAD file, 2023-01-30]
case/led_matrix_64x32/export/bottom_support.3mf
125.8 x 132.5 x 14.0 mm

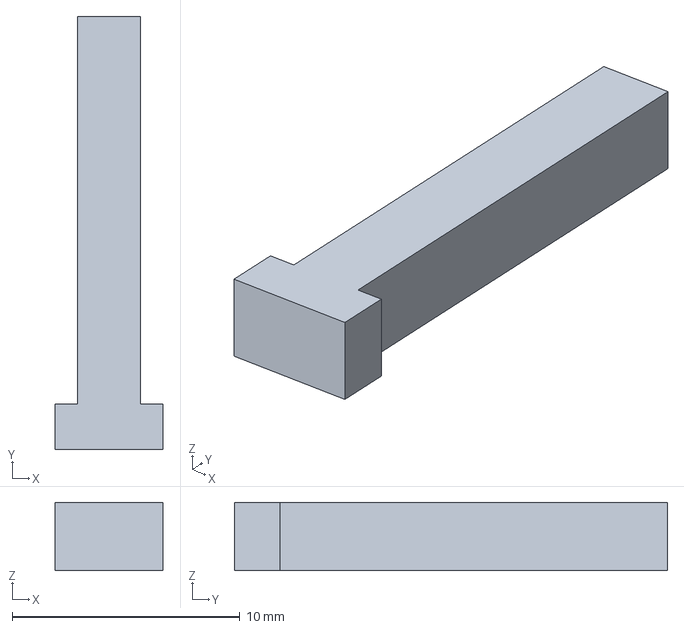
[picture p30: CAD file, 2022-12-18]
case/dotstar_8x8/3mf/button_peg_shaft.3mf
4.75 x 19.0 x 3.00 mm

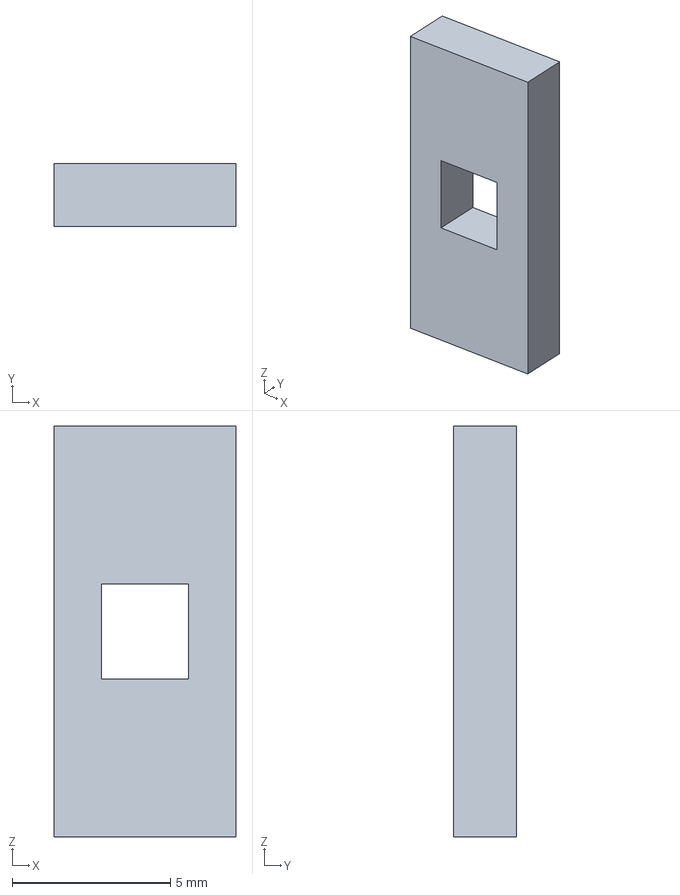
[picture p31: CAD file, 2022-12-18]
case/dotstar_8x8/3mf/button_peg_backing.3mf
5.75 x 2.00 x 13.0 mm

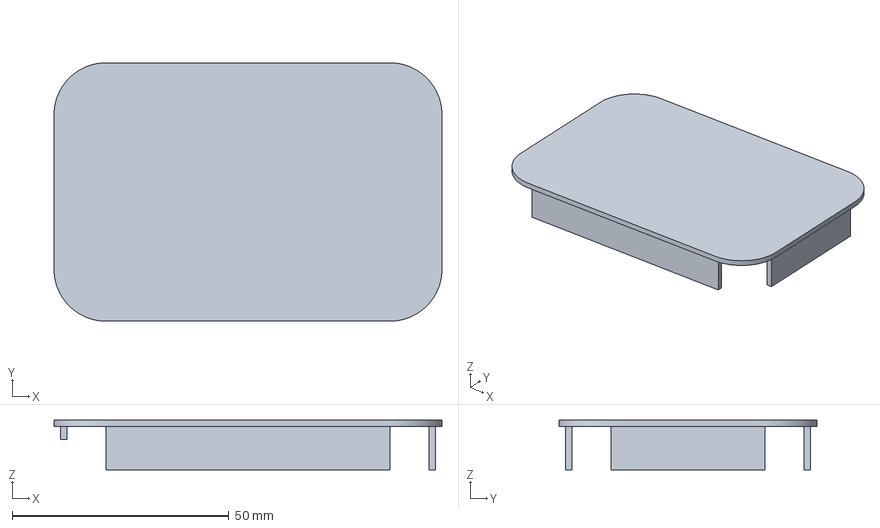
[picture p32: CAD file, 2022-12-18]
case/dotstar_8x8/3mf/top_cover.3mf
89.5 x 59.6 x 11.5 mm

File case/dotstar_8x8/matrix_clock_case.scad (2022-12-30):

use <dep/mattwach/util.scad>
include <lib/matrix_clock_assembled_board.scad>
include <dep/mattwach/vitamins/electronics/adafruit_dotstar_8x8_matrix.scad>

module matrix_clock_case() {
  overlap = 0.01;

  button_slot_width = 3;
  button_slot_xoffset = 24.3;
  button_slot_zoffset = 14;
  button_slot_span = 14.5;
  button_peg_height = 3;
  button_peg_width = button_slot_width - 0.25;
  button_peg_length = 19;

  case_bottom_thickness = 2;
  board_zpad = case_bottom_thickness + 4;  // clearance for bolts and buttons
  board_xypad = 1;
  case_fillet_radius = 12;
  case_shell_thickness = 1.5;
  base_zsize = board_zpad + 19.5 + 5 * 2 - case_shell_thickness;
  case_ysize = MATRIX_CLOCK_PCB_WIDTH + case_shell_thickness * 2 + board_xypad * 2;
  case_xsize = MATRIX_CLOCK_PCB_LENGTH + board_xypad * 2 + case_fillet_radius * 2;
  case_xbase = -board_xypad - case_fillet_radius;
  case_ybase = -case_shell_thickness - board_xypad;

  module base(height, inset) {
    x1 = -board_xypad + inset;
    x2 = MATRIX_CLOCK_PCB_LENGTH + board_xypad - inset;
    y1 = case_fillet_radius - case_shell_thickness - board_xypad + inset;
    y2 = MATRIX_CLOCK_PCB_WIDTH - case_fillet_radius + case_shell_thickness + board_xypad - inset;
    //txy(-case_fillet_radius - board_xypad,
    //  -case_shell_thickness - board_xypad)
    //  cube([case_xsize, case_ysize, height/2]);
    hull() {
      txy(x1, y1) cylinder(r=case_fillet_radius, h=height);
      txy(x1, y2) cylinder(r=case_fillet_radius, h=height);
      txy(x2, y1) cylinder(r=case_fillet_radius, h=height);
      txy(x2, y2) cylinder(r=case_fillet_radius, h=height);
    }
  }

  module clock_base() {
    led_matrix_z = 5;
    led_matrix_ypad = 2;

    module base_shell() {
      mounting_post_hole_x1 = 59.9;
      mounting_post_hole_y1 = 3.7;
      mounting_post_hole_x2 = 6.9;
      mounting_post_hole_y2 = 50.7;
      module mounting_post(is_hole) {
        mounting_post_hole_size = 1.85;
        mounting_post_diameter = mounting_post_hole_size + 4;
        if (is_hole) {
          tz(-overlap) cylinder(
              d=mounting_post_hole_size,
              h=board_zpad + overlap * 2);
        } else {
          tz(case_bottom_thickness - overlap) cylinder(
              d=mounting_post_diameter, h=board_zpad - case_bottom_thickness);
        }
      }

      module pcb_mounting_posts() {
        txy(mounting_post_hole_x1, mounting_post_hole_y1) mounting_post(false);
        txy(mounting_post_hole_x2, mounting_post_hole_y2) mounting_post(false);
        txy(3,3) mounting_post(false);
        txy(60.5,51.5) mounting_post(false);
      }

      module mounting_holes() {
        txy(mounting_post_hole_x1, mounting_post_hole_y1) mounting_post(true);
        txy(mounting_post_hole_x2, mounting_post_hole_y2) mounting_post(true);
      }

      module button_access_holes() {
        access_hole_diameter = 15;
        module access_hole() {
          tz(-overlap) cylinder(
              d=access_hole_diameter,
              h=case_bottom_thickness + overlap * 2);
        }
        module bootsel_hole() {
          txy(47, 33) access_hole();
        }
        module reset_hole() {
          txy(29, 48) access_hole();
        }
        bootsel_hole();
        reset_hole();
      }

      module usb_access_hole() {
        usb_access_hole_width = 14;
        usb_access_hole_depth = 17;
        usb_access_hole_height = 8;
        usb_access_hole_yoffest = 36.5;
        union() {
          translate([
              case_xbase + case_xsize - usb_access_hole_depth + usb_access_hole_width / 2,
              usb_access_hole_yoffest,
              -overlap]) cylinder(
                d=usb_access_hole_width,
                h=case_bottom_thickness + overlap * 2);
          translate([
              case_xbase + case_xsize - usb_access_hole_depth + usb_access_hole_width / 2,
              usb_access_hole_yoffest - usb_access_hole_width / 2,
              -overlap]) cube([
                usb_access_hole_depth - usb_access_hole_width / 2 + overlap,
                usb_access_hole_width,
                usb_access_hole_height]);
        }
      }

      module led_matrix_mount() {
        mounting_post_height = led_matrix_ypad + DOTSTAR_8X8_THICKNESS - DOTSTAR_8X8_PCB_THICKNESS;
        mounting_post_length = DOTSTAR_8X8_BASE_WIDTH;
        mounting_post_width = DOTSTAR_8X8_TAB_WIDTH - 1;
        module matrix_mounting_post() {
          module matrix_mounting_hole() {
            matrix_hole_diameter = 2.35;
            tz(-overlap) cylinder(
                d=matrix_hole_diameter, h=mounting_post_height + overlap * 2);
          }
          module post() {
            cylinder(d=mounting_post_width, h=mounting_post_height);
          }

          translate([
              case_xbase + mounting_post_height + case_shell_thickness,
              MATRIX_CLOCK_PCB_WIDTH / 2 + DOTSTAR_8X8_WIDTH_WITH_TABS / 2 - DOTSTAR_8X8_TAB_WIDTH / 2,
              led_matrix_z + DOTSTAR_8X8_TAB_WIDTH / 2]) ry(-90) difference() {
            post();
            matrix_mounting_hole();
            tx(DOTSTAR_8X8_BOLT_SPAN) matrix_mounting_hole();
          }
        }

        matrix_mounting_post();
        ty(-DOTSTAR_8X8_WIDTH_WITH_TABS + DOTSTAR_8X8_TAB_WIDTH) matrix_mounting_post();
        tz(DOTSTAR_8X8_BOLT_SPAN) matrix_mounting_post();
        ty(-DOTSTAR_8X8_WIDTH_WITH_TABS + DOTSTAR_8X8_TAB_WIDTH) tz(DOTSTAR_8X8_BOLT_SPAN) matrix_mounting_post();
      }

      module button_slots() {
        module button_slot() {
          button_slot_height = 4 + button_peg_height;

          translate([
              case_xbase + button_slot_xoffset,
              case_ybase - overlap,
              button_slot_zoffset]) cube([
                button_slot_width,
                case_shell_thickness + overlap * 2,
                button_slot_height]);
        }

        button_slot();
        tx(button_slot_span) button_slot();
      }

      difference() {
        union() {
          difference() {
            base(base_zsize, 0);
            tz(case_bottom_thickness) base(base_zsize, case_shell_thickness);
          }
          pcb_mounting_posts();
          led_matrix_mount();
        }
        mounting_holes();
        button_access_holes();
        usb_access_hole();
        button_slots();
      }
    }

    module button_peg() {
      button_peg_zoffset = button_slot_zoffset + 3;
      button_peg_yoffset = 2;
      button_peg_backing_thickness = 2;
      button_peg_backing_xpad = 1.5;
      button_peg_backing_zpad = 5;
      module button_peg_shaft() {
        button_peg_front_xpad = 1;
        module main_peg() {
          cube([
              button_peg_width,
              button_peg_length,
              button_peg_height]);
        }
        module front_retainer() {
          translate([
              -button_peg_front_xpad,
              0,
              0]) cube([
                button_peg_width + button_peg_front_xpad * 2,
                button_peg_yoffset,
                button_peg_height]);
        }
        color("green") union() {
          main_peg();
          front_retainer();
        }
      }

      module button_peg_backing() {
        main_backing_xsize = button_peg_backing_xpad * 2 + button_peg_width;
        main_backing_zsize = button_peg_backing_zpad * 2 + button_peg_height;
        module main_backing() {
          cube([
              main_backing_xsize,
              button_peg_backing_thickness,
              main_backing_zsize]);
        }
        module peg_hole() {
          translate([
              (main_backing_xsize - button_peg_width) / 2,
              -overlap,
              (main_backing_zsize - button_peg_height) / 2]) cube([
                button_peg_width,
                button_peg_backing_thickness + overlap * 2,
                button_peg_height]);
        }
        color("blue") translate([
            -button_peg_backing_xpad,
            button_peg_yoffset + case_shell_thickness,
            -button_peg_backing_zpad]) difference() {
          main_backing();
          peg_hole();
        }
      }

      translate([
          case_xbase + button_slot_xoffset,
          case_ybase - button_peg_yoffset,
          button_peg_zoffset]) {
        button_peg_shaft();
        button_peg_backing();
      }
    }

    module led_matrix() {
      translate([
          case_xbase + DOTSTAR_8X8_THICKNESS + case_shell_thickness + led_matrix_ypad,
          case_ybase + (DOTSTAR_8X8_BASE_WIDTH + case_ysize) / 2, 
          led_matrix_z]) ry(-90) rz(-90) adafruit_dotstar_8x8_matrix();
    }

    tz(board_zpad) matrix_clock_assembled_board();
    led_matrix();    
    color("white", 0.5) base_shell();
    button_peg();
  }

  module top_cover() {
    top_cover_thickness = case_shell_thickness;
    inset_thickness = 1.5;
    insert_zsize = 10;

    module cover() {
      base(top_cover_thickness, 0);
    }
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

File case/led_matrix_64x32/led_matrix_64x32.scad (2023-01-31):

use <lib/mattwach/util.scad>
include <lib/mattwach/vitamins/electronics/led_panel_64x32.scad>
include <lib/mattwach/honeycomb.scad>
include <dep/button_pcb.scad>
include <dep/main_pcb.scad>

overlap = 0.01;

pcb_thickness = 1.6;
pcb_clearance = pcb_thickness + 0.2;
placed_button_pcb_xoffset = 13;
placed_button_pcb_yoffset = 3.5;
placed_button_pcb_zoffset = 3;

back_grid_zsize = 2;
hex_grid_inset = 5;
hex_grid_size = 8;
hex_grid_thickness = 1.5;
support_zsize = 14;
mesh_zsize = 6;
support_side_thickness = 12;
support_length =
  LED_PANEL_64_32_BOLT_HOLE_LOFFSET +
  LED_PANEL_64_32_BOLT_HOLE_LSPAN +
  support_side_thickness / 2; 

module led_panel() {
  rz(90) rx(180) led_panel_64x32();
}

module placed_main_pcb() {
  txy(44.8, 68) rz(-90) main_pcb();
}

module placed_button_pcb() {
  translate([
      placed_button_pcb_xoffset,
      placed_button_pcb_yoffset + pcb_thickness,
      9 + placed_button_pcb_zoffset]) rz(-90) ry(90) button_pcb();
}

module bolt_hole() {
  bolt_hole_inset = 4;
  translate([
      LED_PANEL_64_32_BOLT_HOLE_WOFFSET,
      LED_PANEL_64_32_BOLT_HOLE_LOFFSET,
      -overlap]) union() {
    cylinder(d=3.2, h=support_zsize - bolt_hole_inset + overlap);
    tz(support_zsize - bolt_hole_inset)
      cylinder(d=5.9, h=bolt_hole_inset + overlap * 2);
  }
}

module back_grid() {
  grid_ysize = support_length - 66.7;
  mesh_gap = 0.5;
  module hex_grid() {
    tz(support_zsize - back_grid_zsize) intersection() {
      translate([
          LED_PANEL_64_32_BACK_WIDTH / 2,
          grid_ysize / 2,
          -overlap * 2]) honeycomb([
          LED_PANEL_64_32_BACK_WIDTH,
          LED_PANEL_64_32_BACK_WIDTH,
          back_grid_zsize + overlap * 4], hex_grid_size, hex_grid_thickness);
      translate([
          support_side_thickness + hex_grid_inset,
          hex_grid_inset,
          -overlap]) cube([
            LED_PANEL_64_32_BACK_WIDTH - support_side_thickness * 2 - hex_grid_inset * 2,
            grid_ysize - mesh_gap - hex_grid_inset * 2,
            back_grid_zsize + overlap * 2]);
    }
  }
  module block() {
    translate([
        support_side_thickness - overlap,
        0,
        support_zsize - back_grid_zsize]) cube([
          LED_PANEL_64_32_BACK_WIDTH - support_side_thickness * 2 + overlap * 2,
          grid_ysize - mesh_gap + overlap,
          back_grid_zsize]);
  }
  difference() {
    block();
    hex_grid();
  }
}

module bottom_support() {
  support_arm_yoffset = 66.7;
  support_arm_ysize = 4;
  module left_side() {
    module left_side_main() {
      module main() {
        cube([
            support_side_thickness,
            support_length,
            support_zsize]);
      }

      module pcb_anti_slide_arm() {
        arm_inset = 2;
        xsize = 15;
        xoffset = 44.6;
        translate([
            xoffset - xsize,
            support_arm_yoffset - arm_inset,
            0]) cube([
              xsize,
              support_arm_ysize + arm_inset,
              support_zsize]);
      }

      module pcb_support_arm() {
        support_arm_xoffset = 80;
        support_arm_xsize = 15;
        module pcb_cutout() {
          cutout_yinset = 1.5;
          translate([
              -overlap,
              -overlap,
              -overlap]) cube([
                support_arm_xsize + overlap * 2,
                cutout_yinset + overlap,
                pcb_clearance + overlap]);
        }
        txy(
            support_arm_xoffset,
            support_arm_yoffset) difference() {
          cube([
              support_arm_xsize,
              support_arm_ysize,
              support_zsize]);
          pcb_cutout();
        }
      }

      union() {
        main();
        pcb_anti_slide_arm();
        pcb_support_arm();
      }
    }

    module mesh_cutout() {
      translate([
          -overlap,
          support_length - support_side_thickness + overlap,
          -overlap]) cube([
            support_side_thickness + overlap * 2,
            support_side_thickness + overlap,
            mesh_zsize]);
    }

    module bolt_holes() {
      bolt_hole();
      ty(LED_PANEL_64_32_BOLT_HOLE_LSPAN) bolt_hole();
    }

    difference() {
      left_side_main();
      mesh_cutout();
      bolt_holes();
    }
  }

  module right_side() {
    right_size_xoffset = LED_PANEL_64_32_BACK_WIDTH - support_side_thickness;
    module right_side_main() {
      translate([
          right_size_xoffset,
          0,
          0]) cube([
            support_side_thickness,
            support_length,
            support_zsize]);
    }

    module main_pcb_side_cutout() {
      main_pcb_side_cutout_yoffset = 5.8;
      main_pcb_side_cutout_ysize = 62.5;
      main_pcb_side_cutout_xsize = 1.3;
      translate([
          right_size_xoffset - overlap,
          main_pcb_side_cutout_yoffset,
          -overlap]) cube([
            main_pcb_side_cutout_xsize + overlap,
            main_pcb_side_cutout_ysize,
            pcb_clearance + overlap]);
    }

    module mesh_cutout() {
      translate([
          right_size_xoffset - overlap,
          support_length - support_side_thickness + overlap,
          -overlap]) cube([
            support_side_thickness + overlap * 2,
            support_side_thickness + overlap,
            mesh_zsize]);
    }

    module bolt_holes() {
      tx(LED_PANEL_64_32_BOLT_HOLE_WSPAN) {
        bolt_hole();
        ty(LED_PANEL_64_32_BOLT_HOLE_LSPAN) bolt_hole();
      }
    }

    difference() {
      right_side_main();
      main_pcb_side_cutout();
      mesh_cutout();
      bolt_holes();
    }
  }

  module bottom_side() {
    bottom_side_thickness = 7;
    module main() {
      tx(support_side_thickness - overlap) cube([
            LED_PANEL_64_32_BACK_WIDTH - support_side_thickness * 2 + overlap * 2,
            bottom_side_thickness,
            support_zsize]);
    }

    module main_pcb_cutout() {
      pcb_width = 69.2;
      pcb_inset = 1.2;
      translate([
          LED_PANEL_64_32_BACK_WIDTH - pcb_width - support_side_thickness,
          bottom_side_thickness - pcb_inset,
          -overlap]) cube([
            pcb_width + overlap * 2,
            pcb_inset + overlap,
            pcb_clearance + overlap]);
    }

    module usb_cutout() {
      usb_cutout_width = 17;
      usb_cutout_height = support_zsize - 2;
      usb_cutout_xoffset = 80;
      usb_cutout_fillet = 5;

      module top_corner() {
        translate([
            usb_cutout_fillet,
            0,
            usb_cutout_height - usb_cutout_fillet]) rx(-90) cylinder(r=usb_cutout_fillet, h=bottom_side_thickness + overlap * 2);
      }

      translate([
          usb_cutout_xoffset,
          -overlap,
          -overlap]) hull() {
        cube([
            usb_cutout_width,
            bottom_side_thickness + overlap * 2,
            1]);
        top_corner();
        tx(usb_cutout_width - usb_cutout_fillet * 2) top_corner();
      }
    }

    module button_front_cutout() {
      button_cutout_width = 20.5;
      button_cutout_height = support_zsize - 2;
      button_cutout_xoffset = placed_button_pcb_xoffset + 14;
      button_cutout_fillet = 3;

      module top_corner() {
        translate([
            button_cutout_fillet,
            0,
            button_cutout_height - button_cutout_fillet]) rx(-90) cylinder(r=button_cutout_fillet, h=bottom_side_thickness + overlap * 2);
      }

      translate([
          button_cutout_xoffset,
          -overlap,
          -overlap]) hull() {
        cube([
            button_cutout_width,
            bottom_side_thickness + overlap * 2,
            1]);
        top_corner();
        tx(button_cutout_width - button_cutout_fillet * 2) top_corner();
      }
    }

    module button_back_cutout() {
      pcb_padding = 1;
      pcb_width = 42;
      pcb_height = 9;
      pcb_yoffset = placed_button_pcb_yoffset;
      translate([
          placed_button_pcb_xoffset - pcb_padding,
          pcb_yoffset,
          -overlap]) cube([
            pcb_width + pcb_padding * 2,
            bottom_side_thickness - pcb_yoffset + overlap,
            placed_button_pcb_zoffset + pcb_height + pcb_padding + overlap]);
    }

    module button_bolt_holes() {
      bolt_hole_span = 36;
      module bolt_hole() {
        bolt_hole_xoffset = 3;
        bolt_hole_zoffset = 4;
        translate([
            placed_button_pcb_xoffset + bolt_hole_xoffset,
            -overlap,
            placed_button_pcb_zoffset + bolt_hole_zoffset]) rx(-90) cylinder(d=1.85, h=bottom_side_thickness + overlap * 2);
      }

      bolt_hole();
      tx(bolt_hole_span) bolt_hole();
    }

    difference() {
      main();
      main_pcb_cutout();
      usb_cutout();
      button_front_cutout();
      button_back_cutout();
      button_bolt_holes();
    }
  }

  union() {
    left_side();
    right_side();
    bottom_side();
    ty(support_arm_yoffset) back_grid();
  }
}
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

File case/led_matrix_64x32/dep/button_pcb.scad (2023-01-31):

use <../lib/mattwach/util.scad>
include <../lib/NopSCADlib/core.scad>
include <../lib/NopSCADlib/vitamins/buttons.scad>
include <../lib/NopSCADlib/vitamins/pin_headers.scad>

module button_pcb() {
  pcb_zsize = 1.6;

  module pcb() {
    rz(90) color("#262") import("dep/button_pcb_kicad.stl");
  }

  module buttons() {
    module button() {
      translate([
          4.65,
          18.6,
          pcb_zsize
      ]) square_button(button_6mm);
    }

    button();
    ty(10.7) button();
  }

  module pins() {
    translate([
        4.5,
        9,
        0]) rz(180) ry(180) pin_header(2p54header, 3, 1, right_angle=true);
  }

  pcb();
  buttons();
  pins();
}

/*
$fa=2;
$fs=0.2;
button_pcb();
*/

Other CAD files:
case/led_matrix_64x32/dep/main_pcb.scad
case/dotstar_8x8/dep/mattwach/vitamins/electronics/adafruit_dotstar_8x8_matrix.scad
case/dotstar_8x8/dep/mattwach/vitamins/electronics/buttons.scad

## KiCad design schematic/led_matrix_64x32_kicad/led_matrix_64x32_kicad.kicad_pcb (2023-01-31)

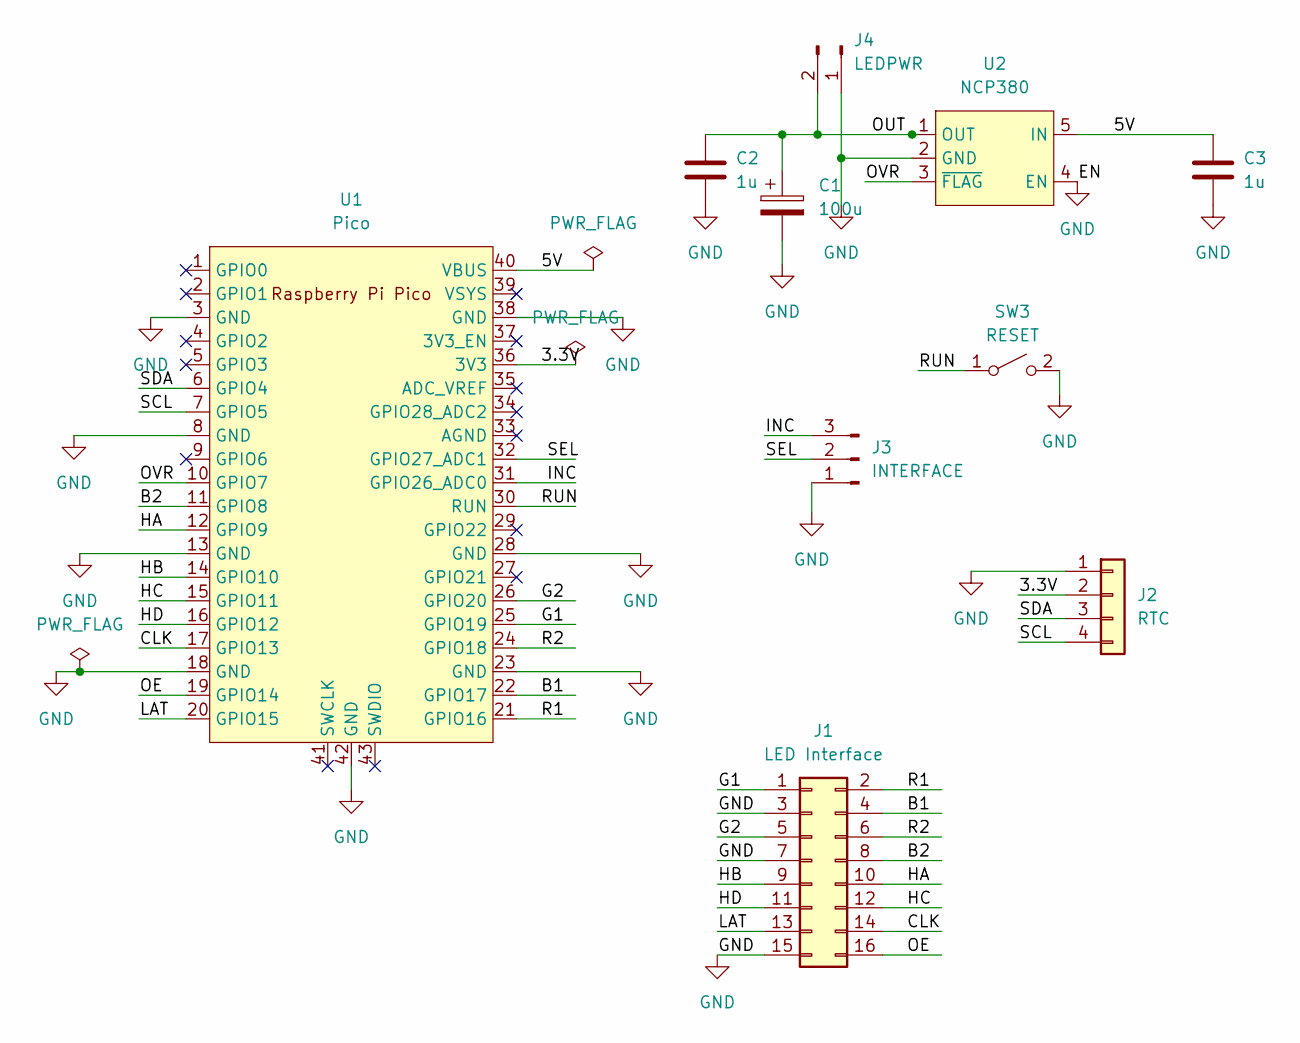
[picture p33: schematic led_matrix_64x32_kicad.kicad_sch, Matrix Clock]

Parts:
C1: 100u; CP_Radial_D6.3mm_P2.50mm
C2, C3: 1u; C_0805_2012Metric_Pad1.18x1.45mm_HandSolder
J1: LED Interface; PinHeader_2x08_P2.54mm_Vertical
J2: RTC; PinHeader_1x04_P2.54mm_Vertical
J3: INTERFACE; PinHeader_1x03_P2.54mm_Horizontal
J4: LEDPWR; PinHeader_1x02_P2.54mm_Horizontal
SW3: RESET; SMD_Button_6mm_3_5mm
U1: Pico; RPi_Pico_SMD_TH
U2: NCP380; TSOP-5_1.65x3.05mm_P0.95mm

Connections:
/3.3V: J2.2, U1.36 (3V3)
/5V: C3.1, U1.40 (VBUS), U2.5 (IN)
/B1: J1.4, U1.22 (GPIO17)
/B2: J1.8, U1.11 (GPIO8)
/CLK: J1.14, U1.17 (GPIO13)
/G1: J1.1, U1.25 (GPIO19)
/G2: J1.5, U1.26 (GPIO20)
/HA: J1.10, U1.12 (GPIO9)
/HB: J1.9, U1.14 (GPIO10)
/HC: J1.12, U1.15 (GPIO11)
/HD: J1.11, U1.16 (GPIO12)
/INC: J3.3, U1.31 (GPIO26_ADC0)
/LAT: J1.13, U1.20 (GPIO15)
/OE: J1.16, U1.19 (GPIO14)
/OUT: C1.1, C2.1, J4.2, U2.1 (OUT)
/OVR: U1.10 (GPIO7), U2.3 (~FLAG)
/R1: J1.2, U1.21 (GPIO16)
/R2: J1.6, U1.24 (GPIO18)
/RUN: SW3.1 (A), U1.30 (RUN)
/SCL: J2.4, U1.7 (GPIO5)
/SDA: J2.3, U1.6 (GPIO4)
/SEL: J3.2, U1.32 (GPIO27_ADC1)

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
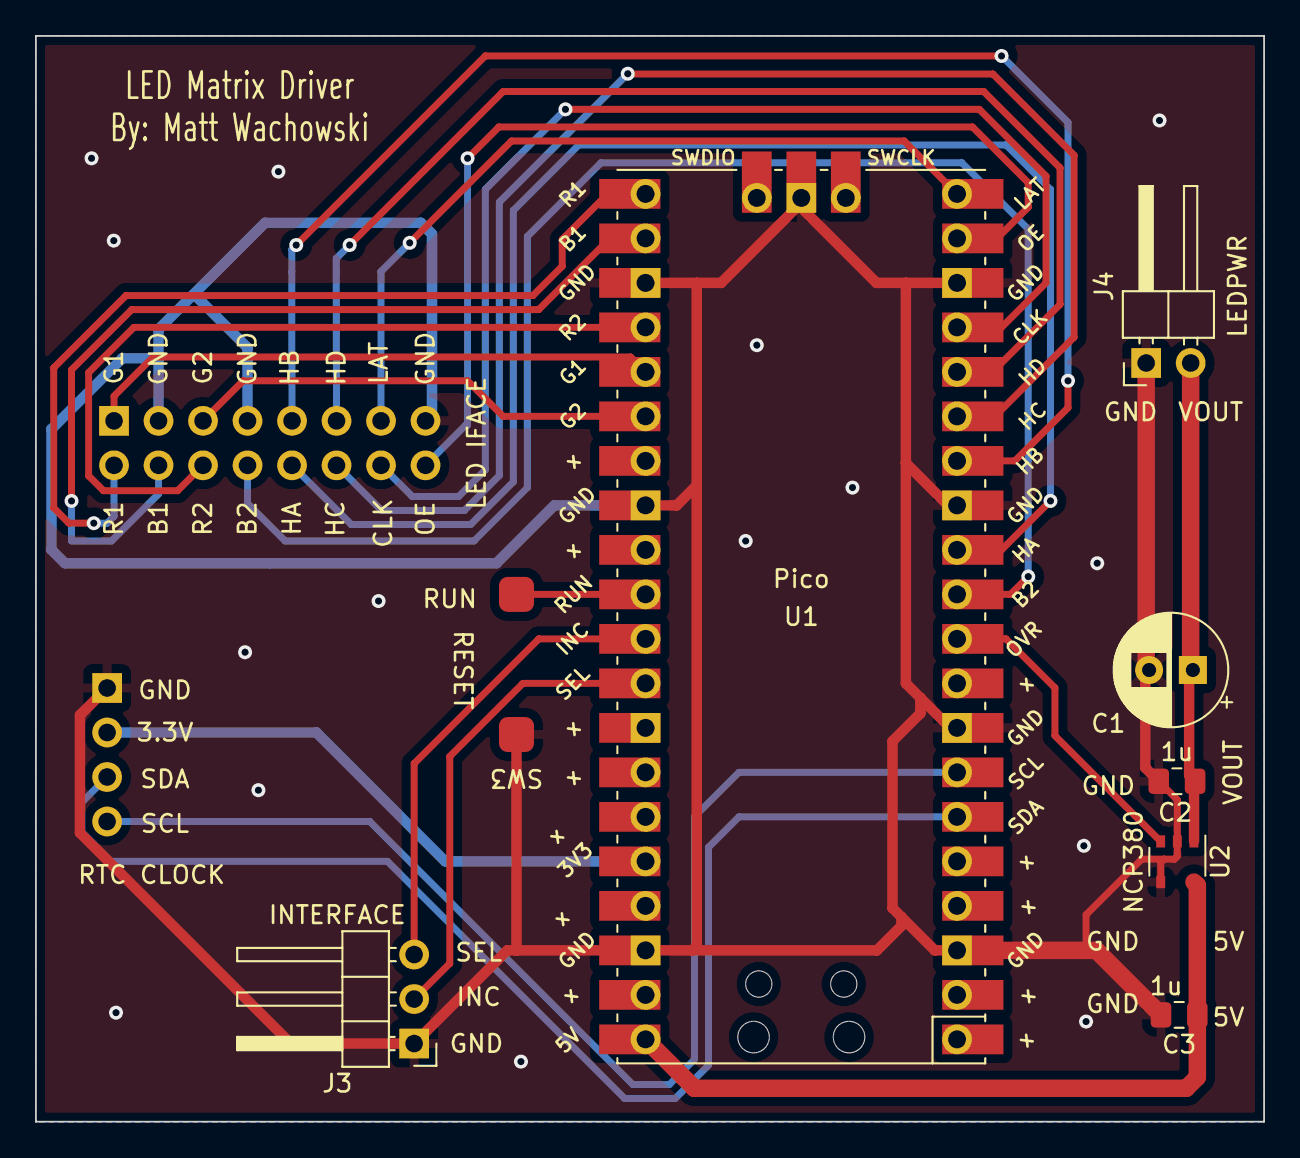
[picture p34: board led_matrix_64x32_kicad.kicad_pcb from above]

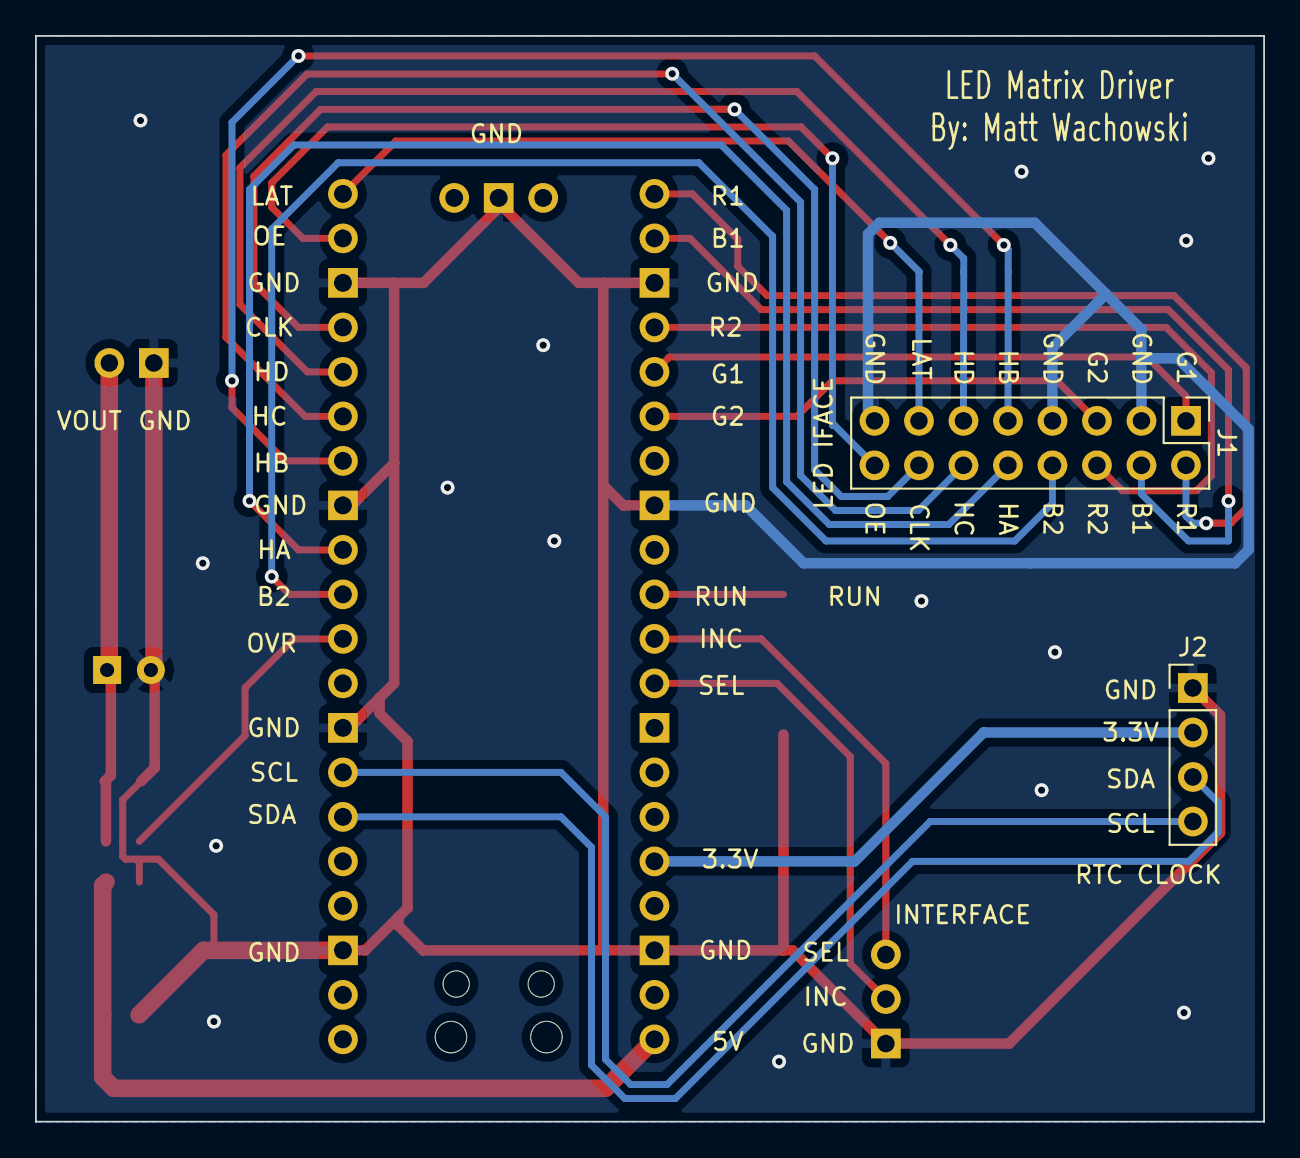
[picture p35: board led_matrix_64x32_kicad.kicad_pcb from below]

Board: 2 copper layers, 70.1 x 62.0 mm, 10 parts (2 on the bottom side), 23 nets.

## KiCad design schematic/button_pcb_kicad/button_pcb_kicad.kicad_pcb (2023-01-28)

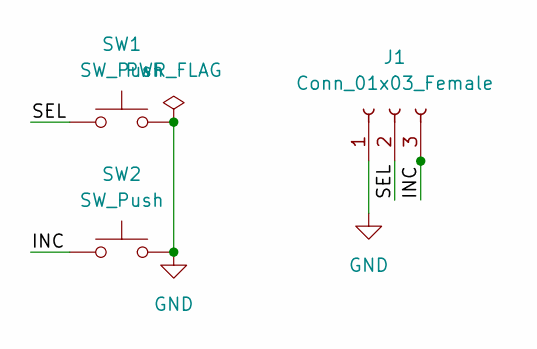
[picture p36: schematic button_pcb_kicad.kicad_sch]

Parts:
J1: Conn_01x03_Female; SMD_Pad_1x03_2mm
SW1, SW2: SW_Push; SW_PUSH_6mm_H4.3mm

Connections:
/INC: J1.3, SW2.1
/SEL: J1.2, SW1.1
GND: J1.1, SW1.2, SW2.2

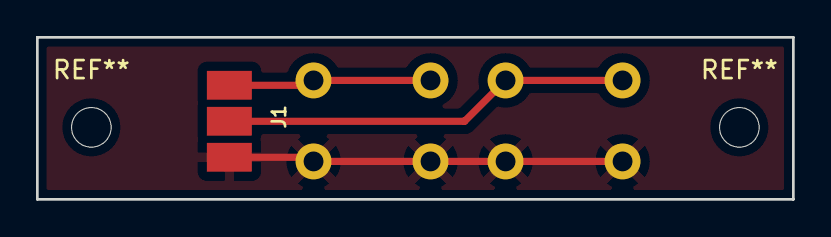
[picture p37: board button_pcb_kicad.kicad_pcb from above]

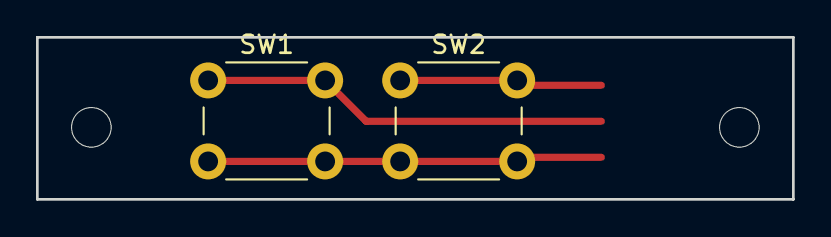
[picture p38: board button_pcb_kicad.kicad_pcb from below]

Board: 2 copper layers, 42.0 x 9.0 mm, 3 parts (2 on the bottom side), 3 nets.

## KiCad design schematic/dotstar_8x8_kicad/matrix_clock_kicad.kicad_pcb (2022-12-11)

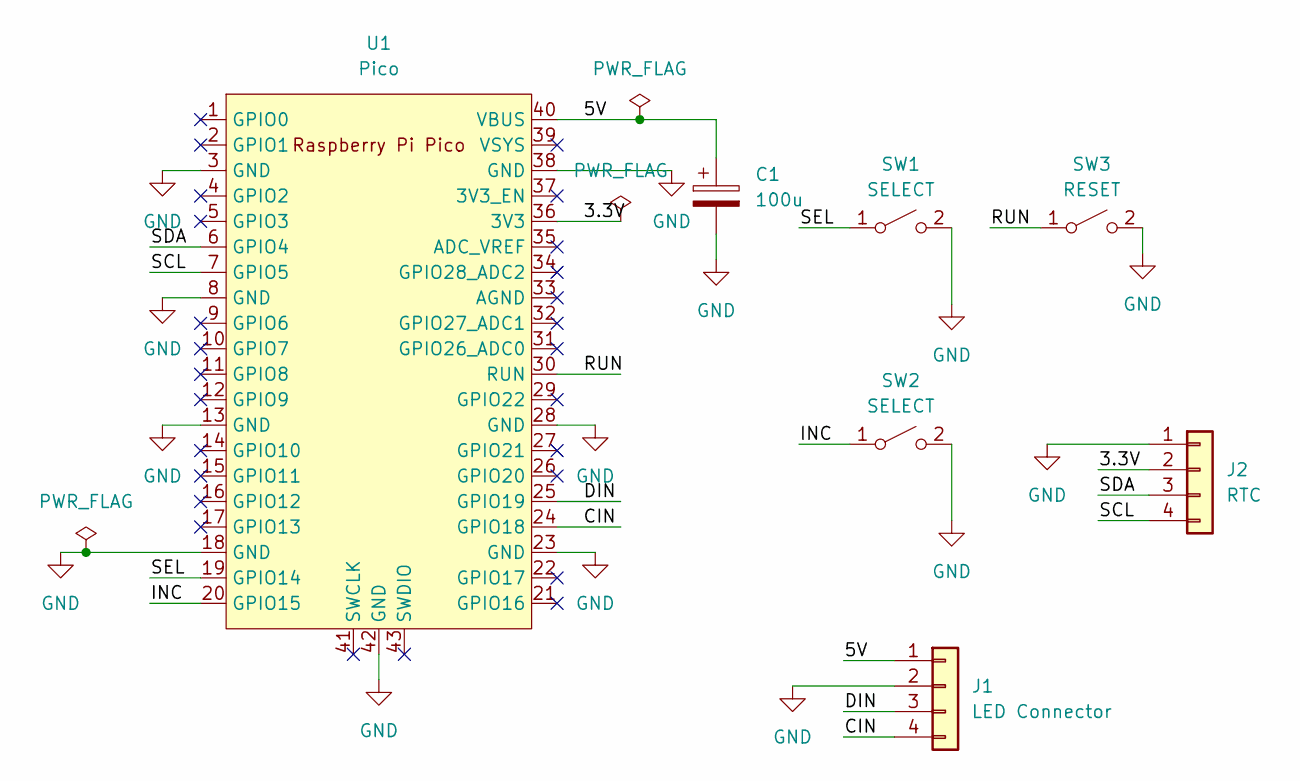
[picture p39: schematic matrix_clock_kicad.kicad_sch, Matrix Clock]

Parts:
C1: 100u; CP_Radial_D6.3mm_P2.50mm
J1: LED Connector; PinHeader_1x04_P2.54mm_Vertical
J2: RTC; PinHeader_1x04_P2.54mm_Vertical
SW1, SW2: SELECT; SW_PUSH-12mm
SW3: RESET; SMD_Button_6mm_3_5mm
U1: Pico; RPi_Pico_SMD_TH

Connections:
/3.3V: J2.2, U1.36 (3V3)
/5V: C1.1, J1.1, U1.40 (VBUS)
/CIN: J1.4, U1.24 (GPIO18)
/DIN: J1.3, U1.25 (GPIO19)
/INC: SW2.1 (A), U1.20 (GPIO15)
/RUN: SW3.1 (A), U1.30 (RUN)
/SCL: J2.4, U1.7 (GPIO5)
/SDA: J2.3, U1.6 (GPIO4)
/SEL: SW1.1 (A), U1.19 (GPIO14)
GND: C1.2, J1.2, J2.1, SW1.2 (B), SW2.2 (B), SW3.2 (B), U1.3 (GND), U1.8 (GND), U1.13 (GND), U1.18 (GND), U1.23 (GND), U1.28 (GND), U1.38 (GND), U1.42 (GND)

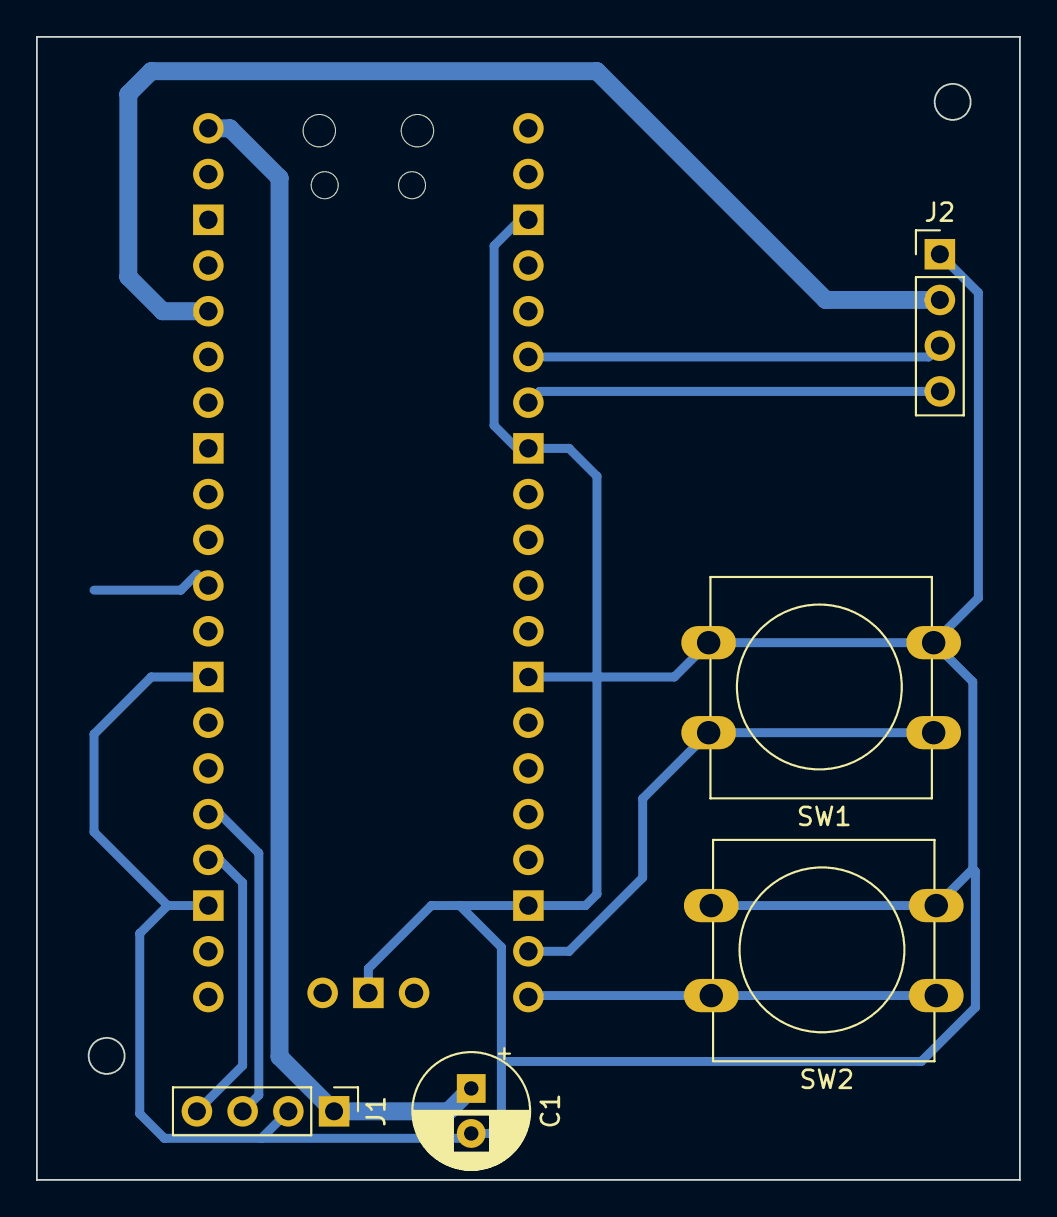
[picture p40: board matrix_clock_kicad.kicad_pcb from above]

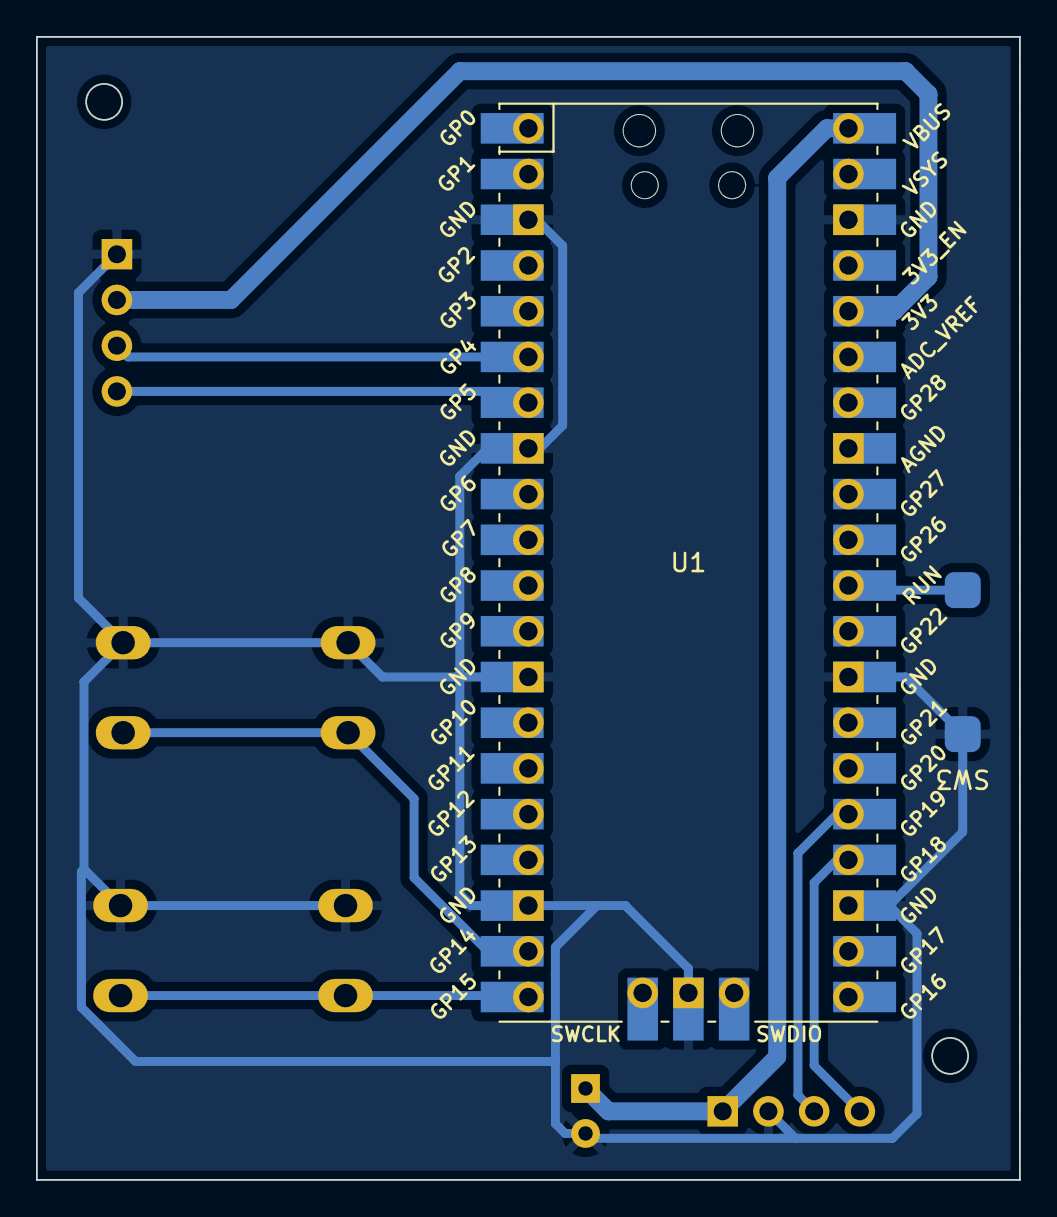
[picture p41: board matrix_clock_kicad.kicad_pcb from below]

Board: 2 copper layers, 54.6 x 63.5 mm, 7 parts (2 on the bottom side), 10 nets.

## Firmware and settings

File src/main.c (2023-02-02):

// Matrix clock
//
// By: Matt Wachowski

#include "pico/stdlib.h"
#include <string.h>
#include "clock.h"
#include "clock_render.h"
#include "clock_settings.h"
#include "led_matrix.h"
#include "monitor.h"
#include "buttons.h"
#include "set_time_low_res.h"
#include "set_time_high_res.h"

#if defined(led_matrix_dotstar)
  #define SET_TIME_RENDER set_time_lowres_render
#elif defined(led_matrix_64x32)
  #define SET_TIME_RENDER set_time_highres_render
#else
  #error Unknown LED_MATRIX_SOURCE
#endif

#define TIME_UPDATE_FRAMES (1000/FRAME_DELAY_MS)
#define LED_PIN PICO_DEFAULT_LED_PIN

// set to 1 if the user is setting the time
uint8_t setting_time;

// format is 0xIIRRGGBB  See led_matrix.h for mor details.
uint32_t led[LED_MATRIX_COUNT];
uint16_t time_hhmm;  // a cache of the time to avoid calling for it as much

struct Monitor monitor;

static inline uint32_t uptime_ms() {
  return to_ms_since_boot(get_absolute_time());
}

// Initialization function
static void init(void) {
  setting_time = 0;
  gpio_init(LED_PIN);
  gpio_set_dir(LED_PIN, GPIO_OUT);
  clock_settings_init();
  led_matrix_init();
  clock_init();
  buttons_init();
  sleep_ms(50);
  time_hhmm = clock_get_time();
  monitor_init(&monitor);
}

// Updates time_hhmm periocially (based on TIME_UPDATE_FRAMES)
static void maybe_update_time(uint32_t frame_idx) {
  if ((frame_idx % TIME_UPDATE_FRAMES) == 0) {
    time_hhmm = clock_get_time();
  }
}

// called repeatedly by main to render a frame
static uint32_t render(uint32_t frame_idx) {
  uint32_t t1 = uptime_ms();
  maybe_update_time(frame_idx);
  memset(led, 0, sizeof(led));
  uint8_t toggle_setting_time = 0;
  uint8_t buttons = buttons_get();
  buttons |= clock_settings_poll(time_hhmm, monitor.last_fps);
  if (setting_time) {
    toggle_setting_time = SET_TIME_RENDER(
          led, buttons, frame_idx, time_hhmm, clock_settings());
  } else {
    toggle_setting_time = clock_render(
          led, buttons, frame_idx, time_hhmm, clock_settings());
  }
  ++frame_idx;
  if (toggle_setting_time) {
    setting_time = !setting_time;
    frame_idx = 0;
  }
  led_matrix_render(led);
  // calculate tdelta to get a smooth frame rate, even if the loop time
  // varies.
  uint32_t tdelta = uptime_ms() - t1;
  if (tdelta < FRAME_DELAY_MS) {
    sleep_ms(FRAME_DELAY_MS - tdelta);
  }
  return frame_idx;
}

// Program starting point
int main() {
  init();
  uint32_t frame_idx = 0;
  while (1) {
    frame_idx = render(frame_idx);
    gpio_put(LED_PIN, is_current_over());
    monitor_frame(&monitor);
  }
}

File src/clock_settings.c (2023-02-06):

#include "clock_settings.h"
#include "hardware/flash.h"
#include "hardware/sync.h"
#include "uart_console/console.h"
#include "buttons.h"
#include "colors.h"
#include "clock.h"
#include "clock_render.h"
#include "led_matrix.h"
#include <stdio.h>
#include <string.h>
#include <stdlib.h>

#if defined(led_matrix_dotstar)
#define DEFAULT_BRIGHTNESS_STEP 3
#elif defined(led_matrix_64x32)
#define DEFAULT_BRIGHTNESS_STEP 10
#else
#error Unknown LED_MATRIX_SOURCE
#endif

// Set to zero to disable by default
#define DEFAULT_AUTOMODE_MINUTES 11

// brightness is 0-255
#define MIN_BRIGHTNESS 40   // 0-255
#define BRIGHTNESS_STEP_SIZE 20   // 0-255
#define BRIGHTNESS_STEPS 10   // 0-255

#define FLASH_OFFSET (PICO_FLASH_SIZE_BYTES - FLASH_SECTOR_SIZE)
#define FLASH_ADDRESS ((uint8_t*)(XIP_BASE + FLASH_OFFSET))

// Most of the USB-console logic is offloaded into the uart_console
// library.
static struct ConsoleConfig console;
static struct ClockSettings settings;

// next button press
static uint8_t buttons;

// A simple checksum calculation that also incorporates
// CLOCK_SETTINGS_VERSION.  If CLOCK_SETTINGS_VERSION is changed
// then the checksum will fail (by design) until the data
// is rewritten with the updated version.
static uint32_t calc_checksum(const struct ClockSettings* cs) {
  uint8_t* start = ((uint8_t*)cs) + sizeof(uint32_t);
  size_t len = sizeof(struct ClockSettings) - sizeof(uint32_t);
  uint32_t sum = CLOCK_SETTINGS_VERSION * 1000000;
  for (size_t i=0; i<len; ++i) {
    sum += start[i];
  }
  return sum;
}

// saves current settingsw to flash
static void clock_settings_save(const struct ClockSettings* cs) {
  uint8_t buff[FLASH_PAGE_SIZE];
  memset(buff, 0, sizeof(buff));
  memcpy(buff, cs, sizeof(struct ClockSettings));
  struct ClockSettings* settings = (struct ClockSettings*)buff;
  settings->eyecatcher[0] = 'M';
  settings->eyecatcher[1] = 'C';
  settings->eyecatcher[2] = 'L';
  settings->eyecatcher[3] = 'K';
  settings->checksum = calc_checksum(settings);
  led_matrix_stop();
  uint32_t ints = save_and_disable_interrupts();
  flash_range_erase(FLASH_OFFSET, FLASH_SECTOR_SIZE);
  flash_range_program(FLASH_OFFSET, buff, FLASH_PAGE_SIZE);
  printf("Settings Saved\n");
  restore_interrupts (ints);
}

// dumps current sleep settings to the console
static void output_sleep_data(void) {
  const char* sleep_enabled =
      (settings.sleep_time == settings.wake_time) ? "disabled" : "enabled";
  printf("sleep_time = %d (%s)\n", settings.sleep_time, sleep_enabled);
  printf("wake_time = %d (%s)\n", settings.wake_time, sleep_enabled);
}

static void print_enabled_modes(void) {
  printf("auto_mode_change: ");
  if (settings.mode_change_minutes == 0) {
    printf("disabled\n");  
  } else {
    printf(
        "%d min  next:%04d\n",
        settings.mode_change_minutes, clock_render_next_mode_change());
  }
  printf("auto_mode_include: ");
  const uint8_t num_modes = clock_render_num_display_modes() - 1;
  for (uint8_t i=0; i < num_modes; ++i) {
    const uint8_t enabled = settings.enabled_modes & (1 << i);
    printf("%c%s ", enabled ? '+' : '-', clock_render_display_mode_name(i));
  }
  printf("\n");
}

// callback for the "get" shell command
static void get_cmd(uint8_t argc, char* argv[]) {
  printf("brightness = %d\n", settings.brightness_step);
  printf(
      "startup_display_mode = %s\n",
      clock_render_display_mode_name(settings.startup_display_mode));
  output_sleep_data();
  print_enabled_modes();
}

// callback for the "brightness" shell command
static void brightness_cmd(uint8_t argc, char* argv[]) {
  int brightness = 0;
  if (strcmp(argv[0], "0")) {
    brightness = atoi(argv[0]);
    if ((brightness < 0) || (brightness > 10)) {
      printf("Please choose a brightness value between 0 and 10\n");
      return;
    }
  }
  if (brightness != settings.brightness_step) {
    settings.brightness_step = brightness;
    clock_settings_save(&settings);
  }
}

// helper function to parse an integer, returns -1 on failure
static int parse_uint(const char* s) {
  if (*s == '\0') {
    printf("Empty argument\n");
    return -1;
  }
  if ((s[0] == '0') && (s[1] == '\0')) {
    return 0;
  }
  int val = atoi(s);
  if (val <= 0) {
    printf("Invalid value: %d\n", val);
    return -1;
  }
  return val;
}
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

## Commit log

2022-12-07 Replaced logging with console
    [main.c]
2022-12-08 Fixed flash save bug. Fixed brightness command args.
    [clock_settings.c, main.c]
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2022-12-09 Started kicad schematic
    [matrix_clock_kicad.kicad_pcb, matrix_clock_kicad.kicad_sch]
2022-12-11 Completed PCB layout
    [matrix_clock_kicad.kicad_pcb, matrix_clock_kicad.kicad_sch]
2022-12-11 Added gerber and drill exports.
    Some of these will likely need to be mirrored in flatcam.
    [matrix_clock_kicad-B_Cu.gbr, matrix_clock_kicad-Edge_Cuts.gbr, matrix_clock_kicad-NPTH.drl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]
2022-12-11 Saved some plot options
    [matrix_clock_kicad.kicad_pcb]
2022-12-11 Added and mirrored gerber and drills. Fixed drills.
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2022-12-14 Exported step file
    [matrix_clock_kicad_pcb.step, matrix_clock_kicad_pcb.stl]
2022-12-14 Started assembled board
    [matrix_clock_assembled_board.scad]
2022-12-14 Added pi pico
    [matrix_clock_assembled_board.scad]
2022-12-15 Added RTC
    [matrix_clock_assembled_board.scad]
2022-12-15 Added led matrix header.
    [matrix_clock_assembled_board.scad]
2022-12-15 Added interface buttons
    [matrix_clock_assembled_board.scad]
2022-12-15 added reset button
    [matrix_clock_assembled_board.scad]
2022-12-15 Removed pin header from RTC to save on vertical space.
    [matrix_clock_assembled_board.scad]
2022-12-15 Started scad file for the main case
    [matrix_clock_case.scad]
2022-12-15 Don't include button caps.
    I dont have the correct color, they are not the right dimensions and
    the real PSB has slanted bases due to contruction.
2022-12-15 Implemented base_shell
    [matrix_clock_case.scad]
2022-12-15 Added mounting posts.
    [matrix_clock_case.scad]
2022-12-16 Added boot and reset access holes
    [matrix_clock_case.scad]
2022-12-16 Added led_matrix
    [matrix_clock_case.scad]
2022-12-16 Startig to gravitate toward a vertical design.
    [matrix_clock_case.scad]
2022-12-16 Added usb access hole
    [matrix_clock_case.scad]
2022-12-16 Resized case a bit
    [matrix_clock_case.scad]
2022-12-16 wworking on matrix mounting bars and somethig got messed up. Snapshotting so I can step through undos
    [matrix_clock_case.scad]
2022-12-16 Added matrix mounting bars
    [matrix_clock_case.scad]
2022-12-17 Switched matrix mount to minimal post.
    I *think* I want the light leak but well see.
    [matrix_clock_case.scad]
2022-12-17 Added top cover
    [matrix_clock_case.scad]
2022-12-17 Added button pegs
    [matrix_clock_case.scad]
2022-12-17 Updated buttons to make them smaller and have fewer parts
    [matrix_clock_case.scad]
2022-12-17 Adjusted button dimensions.
    [matrix_clock_case.scad]
2022-12-17 Added a hole to the button peg backing plate.
    [matrix_clock_case.scad]
2022-12-18 Added 3mf export files
    [base.3mf, button_peg_backing.3mf, button_peg_shaft.3mf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]
2022-12-18 Added prusa slicer project for reference.
    [prusa_slicer_project.3mf]
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2022-12-21 Fixed matrix render bug where initial colors were incorrect
    [main.c]
2022-12-26 Made 3d printed case stand-alone
    [adafruit_dotstar_8x8_matrix.scad, bom.scad, buttons.scad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]
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2022-12-30 Added firmware example
    [matrix_clock_case.scad]
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2023-01-07 Fixed compile issues with led_matrix_32x64
    [led_matrix_32x64.c]
2023-01-07 Added DEFAULT_BRIGHTNESS_STEP, fixes to led_matrix
    [clock_settings.c, led_matrix_32x64.c]
2023-01-07 Added missing | sign.
    [led_matrix_32x64.c]
2023-01-08 Moving dotstart case into a sub folder
    [adafruit_dotstar_8x8_matrix.scad, base.3mf, bom.scad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]
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2023-01-08 Started schematic for led matrix 32x64
    [led_matrix_32x64_kicad.kicad_sch]
2023-01-08 Some tweaks that improve clock stability AND FPS.
    [led_matrix_32x64.c]
2023-01-08 Fixed flash save hang.
    Multicore needs to be disabled, then properly reenabled.
    [clock_settings.c, led_matrix.h, led_matrix_32x64.c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]
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2023-01-09 Inverted font on y axis
2023-01-10 Invert y on 32x64 display
    [led_matrix_32x64.c]
2023-01-10 Fixed incorrect use of preprocessor to select matrix hardware.
    [clock_settings.c]
2023-01-10 Remove display_mode shell cmd. Fix time setting.
    [clock_settings.c, main.c]
2023-01-13 Fixed typo in button config
    [buttons.c]
2023-01-13 Starting the 32x64 matrix with a copy of the 8x8 dotstar.
    [led_matrix_32x64_kicad.kicad_sch]
2023-01-13 Mapped 32x64 pins to PICO
    [led_matrix_32x64_kicad.kicad_sch]
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2023-01-15 Snapshot before flipping the board
    [led_matrix_32x64_kicad.kicad_pcb, led_matrix_32x64_kicad.kicad_sch]
2023-01-15 New layout is getting closer
    [led_matrix_32x64_kicad.kicad_pcb, led_matrix_32x64_kicad.kicad_sch]
2023-01-15 More progress on PCB
    [led_matrix_32x64_kicad.kicad_pcb, led_matrix_32x64_kicad.kicad_sch]
2023-01-15 Moved RTC clock pins. Worked on labeling.
    [led_matrix_32x64_kicad.kicad_pcb, led_matrix_32x64_kicad.kicad_sch]
2023-01-15 Passing ERC and DRC checks
    [led_matrix_32x64_kicad.kicad_pcb, led_matrix_32x64_kicad.kicad_sch]
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2023-01-27 Added some gerber output settings
    [led_matrix_32x64_kicad.kicad_pcb]
2023-01-27 Added solder paste layer
    [led_matrix_32x64_kicad-F_Paste.gbr, led_matrix_32x64_kicad-job.gbrjob]
2023-01-27 added solder paste svg
    [led_matrix_32x64_kicad.kicad_pcb]
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2023-01-28 Added schematic/pcb for pushbuttons.
    [button_pcb_kicad.kicad_pcb, button_pcb_kicad.kicad_sch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]
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2023-01-30 Start of main_pcb model
    [button_pcb_kicad.stl, main_pcb.scad, main_pcb.stl]
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2023-01-30 Added led interface pins
    [main_pcb.scad]
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2023-01-30 Started main scad file.
    [led_matrix_32x64.scad]
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2023-01-30 Added right side bottom support
    [button_pcb.scad, led_matrix_32x64.scad]
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2023-01-30 added anti slide arm
    [led_matrix_32x64.scad]
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2023-01-30 added pcb cutout to bottom support
    [led_matrix_32x64.scad]
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2023-01-30 Added button interface to bottom support
    [led_matrix_32x64.scad]
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2023-01-30 Added hex grid to top support
    [led_matrix_32x64.scad]
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2023-01-30 Made hanging hold a bit larger
    [led_matrix_32x64.scad]
2023-01-30 Added exported 3d shapes
    [bottom_support.3mf, top_support.3mf]
2023-01-31 update kicad schematin to tie MCP380 enable to ground
    [led_matrix_32x64_kicad.kicad_pcb, led_matrix_32x64_kicad.kicad_sch]
2023-01-31 Hacky fix to top side bolt offset problem
    [led_matrix_32x64.scad]
2023-01-31 Updated .3mf top support file with correct bolt offsets
    [led_matrix_32x64.scad, top_support.3mf]
2023-01-31 Fixed 62_32 typos
    [led_matrix_32x64.scad]
2023-01-31 Make the openscad project self-contained
    [button_pcb.scad, led_matrix_32x64.scad, main_pcb.scad]
2023-01-31 Rename 32x64 to 64x32
    The project was being inconsistent in choosing a name. This finalizes it on a name
    that people will more easily map to the hardware.
    [bottom_support.3mf, button_pcb.scad, button_pcb_kicad.stl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]
2023-02-01 Fixed orientation to reflect new power cable location
    [led_matrix_64x32.c]
2023-02-02 Fixed the mode change calculation
    [clock_settings.c]
2023-02-02 Fixed mode change minute settings bugs.
    [clock_settings.c]
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
